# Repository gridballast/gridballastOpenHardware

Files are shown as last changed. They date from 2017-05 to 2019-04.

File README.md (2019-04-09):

# GridBallast
Open Source Water Heater and Plug Load Controller

Please see the [full documentation](https://docs.google.com/document/d/1fPQ65AeftvWFN1sJrpfoSuw6C1mJJdnNV9FeLzjZJOI/edit) here.

## Controller Board
This is the main board that interfaces with the peripherals.
The board integrate the following modules and features:
* ESP32
* U-Blox NEO-M8T GPS Timing Chip
* SX1276 Radio
* USB programming and debugging
* 2.4" OLED display
* 4 way navigation buttons
* Raspberry Pi connectivity
* 60Hz Frequency Monitor
* RS485 and I2C exposed interfaces
* 2000:1 current transformer input
* Amplified microphone input with phantom power
* Leak detector input

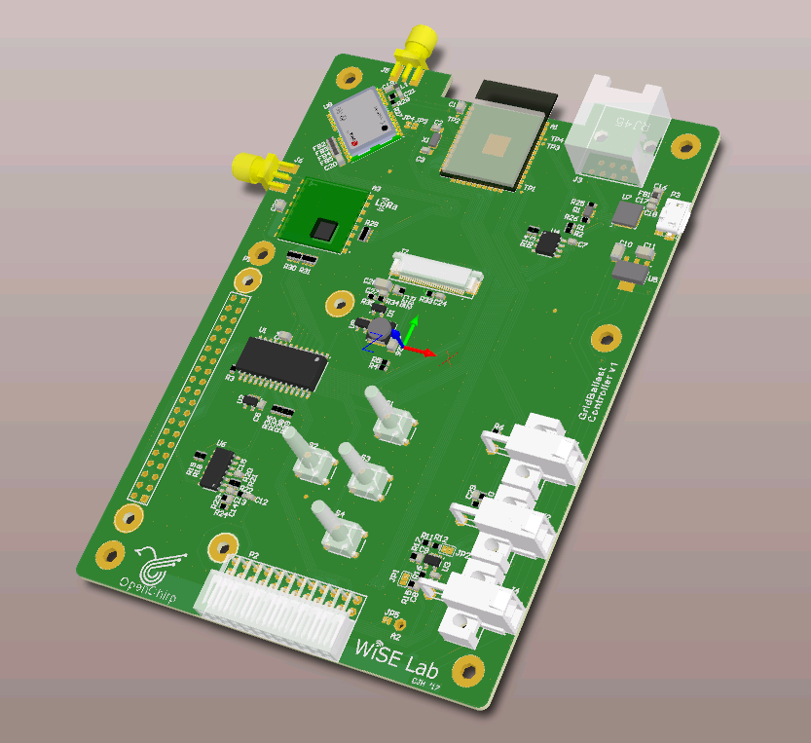
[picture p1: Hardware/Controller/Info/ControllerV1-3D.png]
Controller Board V1 3D


[Interactive 3D View](Hardware/Controller/Info/PCBv1.stl)

## Relay, CT, and Temp Board
This is the accessory board that has two onboard high-power relays, a current transformer, and two analog inputs for temperature sensors.

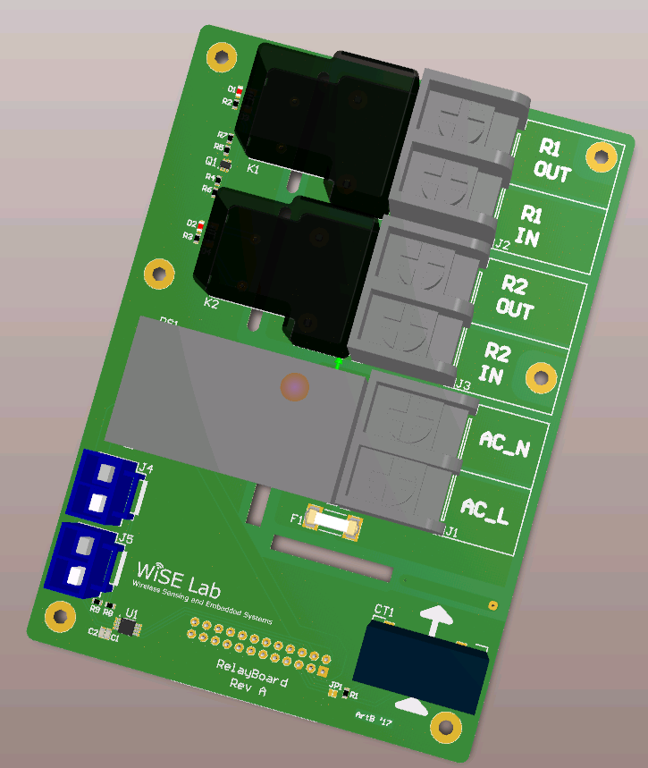
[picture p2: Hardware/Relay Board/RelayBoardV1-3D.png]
Relay Board V1 3D


[Interactive 3D View](Hardware/Relay%20Board/RelayBoardV1.stl)

## CTA2045 and RS485 Board
This small accessory board holds the connector to support CTA2045 and other RS485 communications.
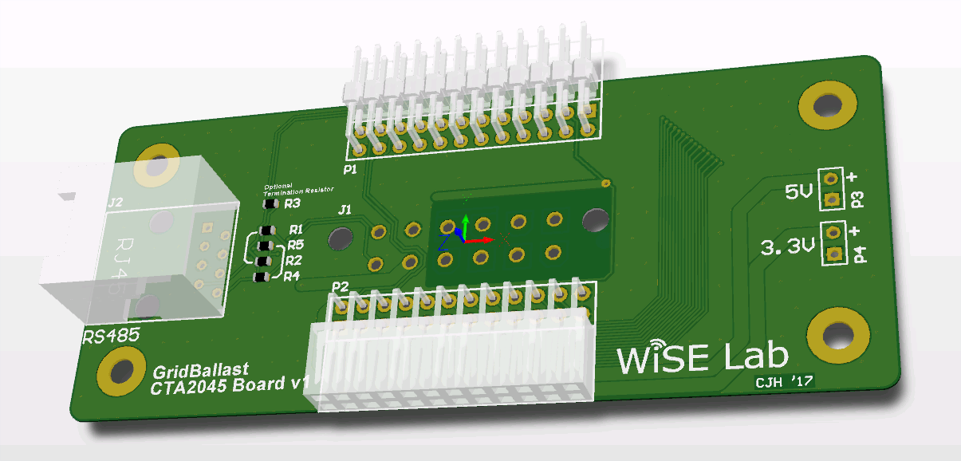
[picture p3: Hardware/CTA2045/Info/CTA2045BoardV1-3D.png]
CTA2045 Board V1 3D


[Interactive 3D View](Hardware/CTA2045/Info/CTA2045v1.stl)

# Getting Started
1. Install the `xtensa-esp32-elf` toolchain by following the instructions here: http://esp-idf.readthedocs.io/en/latest/get-started/#setup-toolchain.
   Make sure the `xtensa-esp32-elf/bin` is added to your `PATH`.
1. Clone the repository
    ```
    $ git clone --recursive https://github.com/WiseLabCMU/gridballast.git
    ```
1. Setup the `IDF_PATH` environment variable by adding the following to your `~/.profile`:
    ```
    export IDF_PATH="<path/to/gridballast>/Support/esp-idf"
    ```
1. Build the controller module
    ```
    $ cd Source/framework
    $ make
    ```
    In the framework configuration, navigate to "Serial flasher config" and select the default serial port. This can be determined by checking which device appears in `/dev` when the controller module is connected via USB. It should start with `/dev/ttyUSB`.
    Save and exit the configuration interface.
1. Flash the controller
    ```
    $ make flash
    ```

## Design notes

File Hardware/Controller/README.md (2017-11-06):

# Description
This is the main appliance controller.

# Fabrication Details
* The main fabrication files and bill of materials are in the [Project Outputs for Controller](Project%20Outputs%20for%20Controller) directory.
* The schematic, pictures, and 3D model are in the [Info](Info) directory.

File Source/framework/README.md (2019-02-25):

# GridBallast

See the README.md file in the upper level 'examples' directory for more information about examples.
This directory is in Support/esp_idf.

# Build Notes
Confirmed to compile on Debian with the lastest compiler, `xtensa-esp32-elf-linux64-1.22.0-80-g6c4433a-5.2.0.tar.gz`,
and the provided `Support/esp-idf` libraries.
`Craig - Feb 25, 2019`

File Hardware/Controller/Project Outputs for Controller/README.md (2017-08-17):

# Board Details
The overall dimensions are 133.2mm x 94mm

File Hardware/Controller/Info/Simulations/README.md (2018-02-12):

# Descriptions
This directory holds the simulation setup and results for some of the more
analog components on the Controller board.

The simulations have been performed in [LTSpice](http://www.linear.com/designtools/software/#LTspice).

# Results Preview

## Microphone and Amplifier with DC Biasing
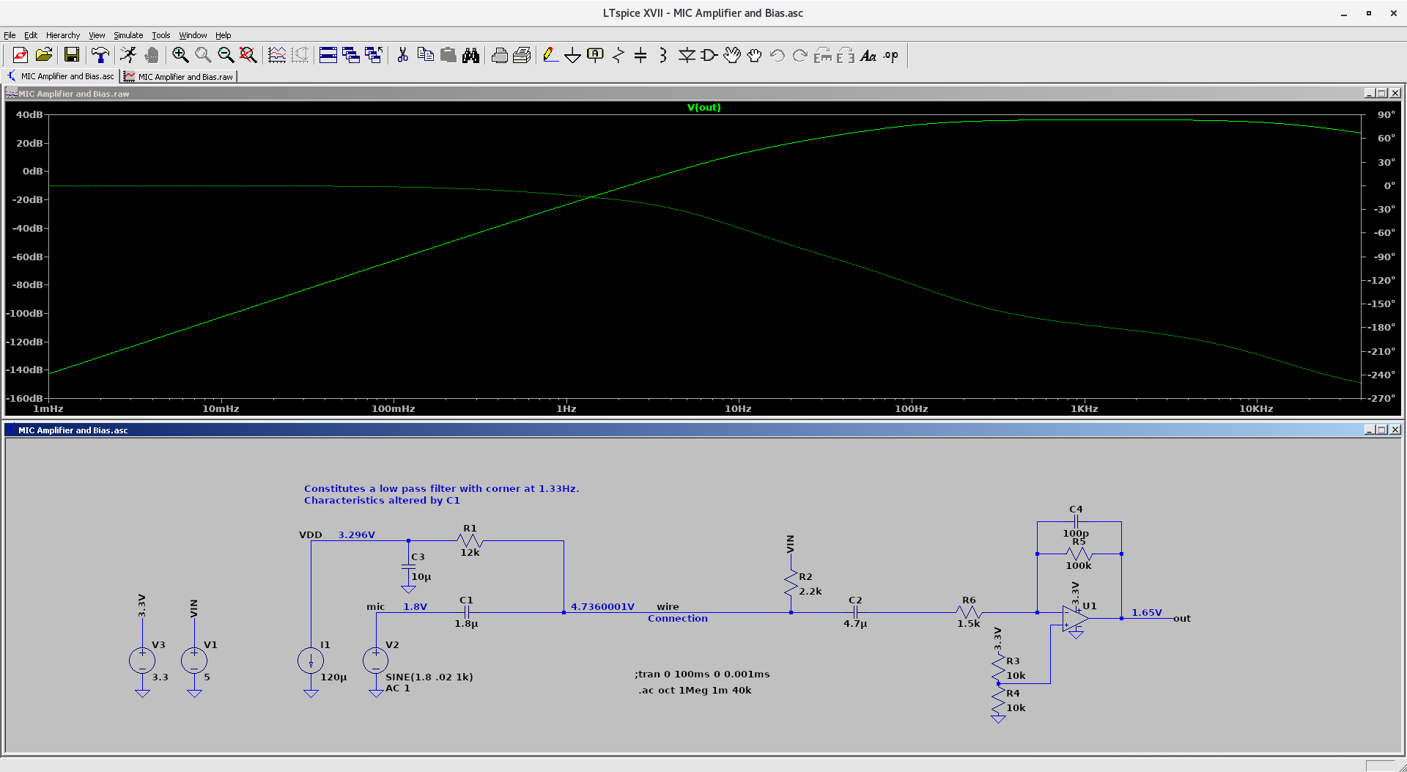
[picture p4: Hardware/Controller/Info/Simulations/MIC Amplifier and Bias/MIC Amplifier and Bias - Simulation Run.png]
MIC Amplifier and Bias


## Current Transformer

### Bias Only - Output Voltage
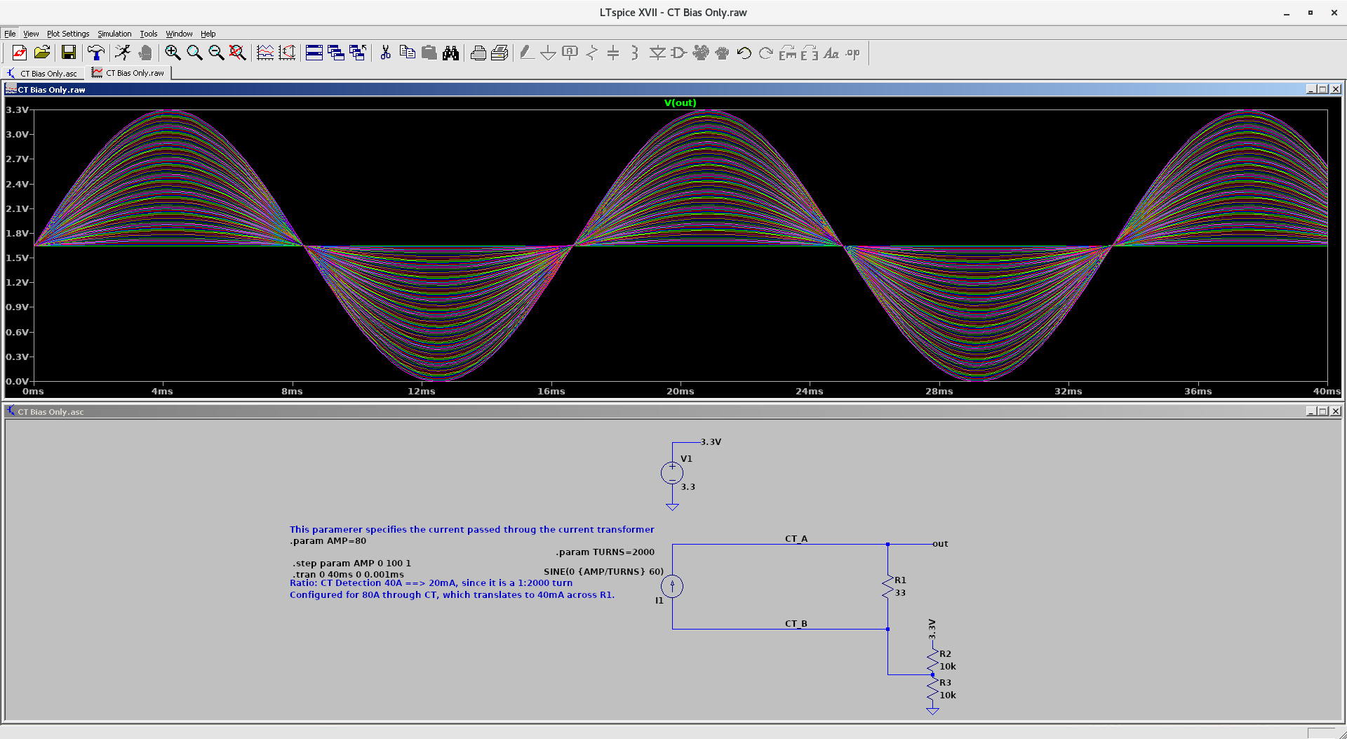
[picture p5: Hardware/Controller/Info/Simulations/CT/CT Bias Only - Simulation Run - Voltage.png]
Voltage


### Bias Only - Current and Output Voltage
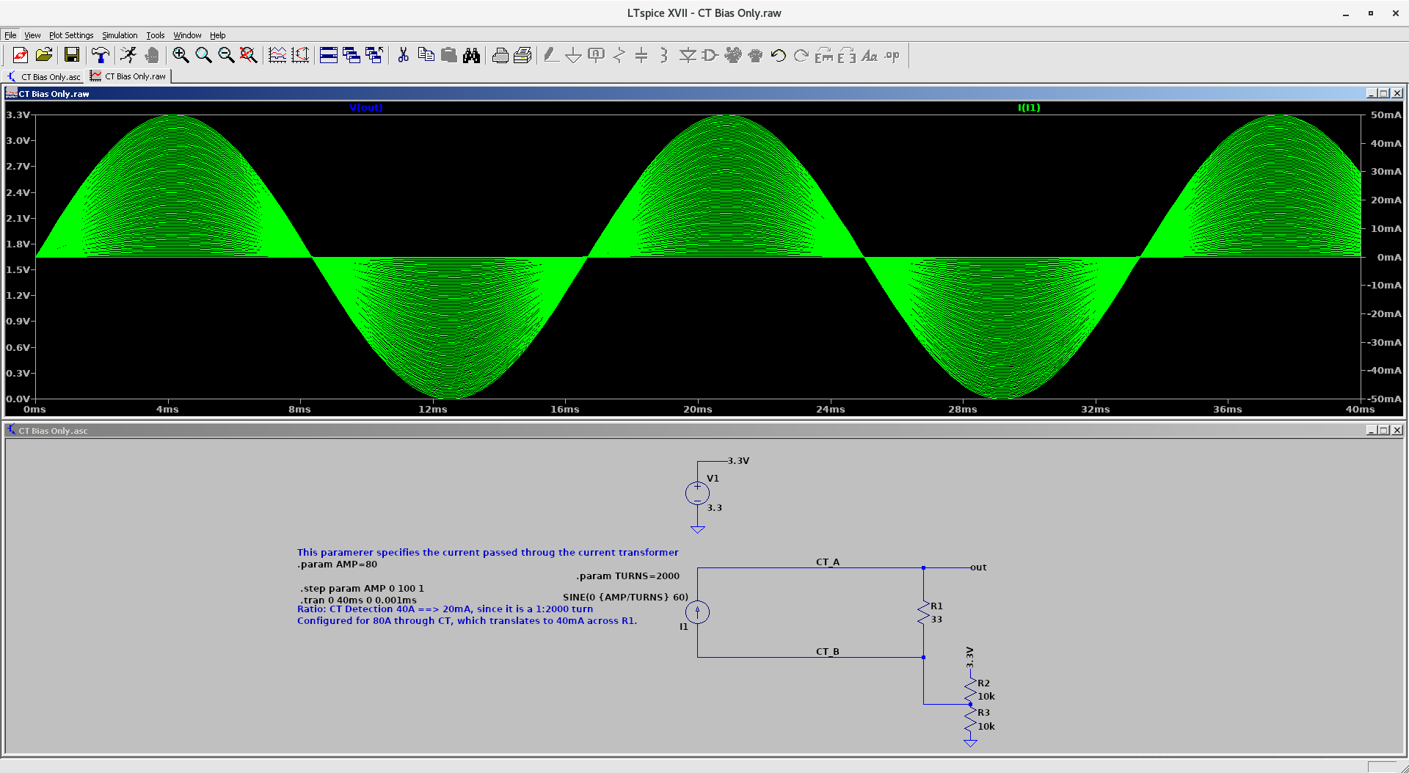
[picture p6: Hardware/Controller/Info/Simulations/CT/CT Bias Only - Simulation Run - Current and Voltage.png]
Current and Voltage


## 60Hz Detector

### Input with Noise
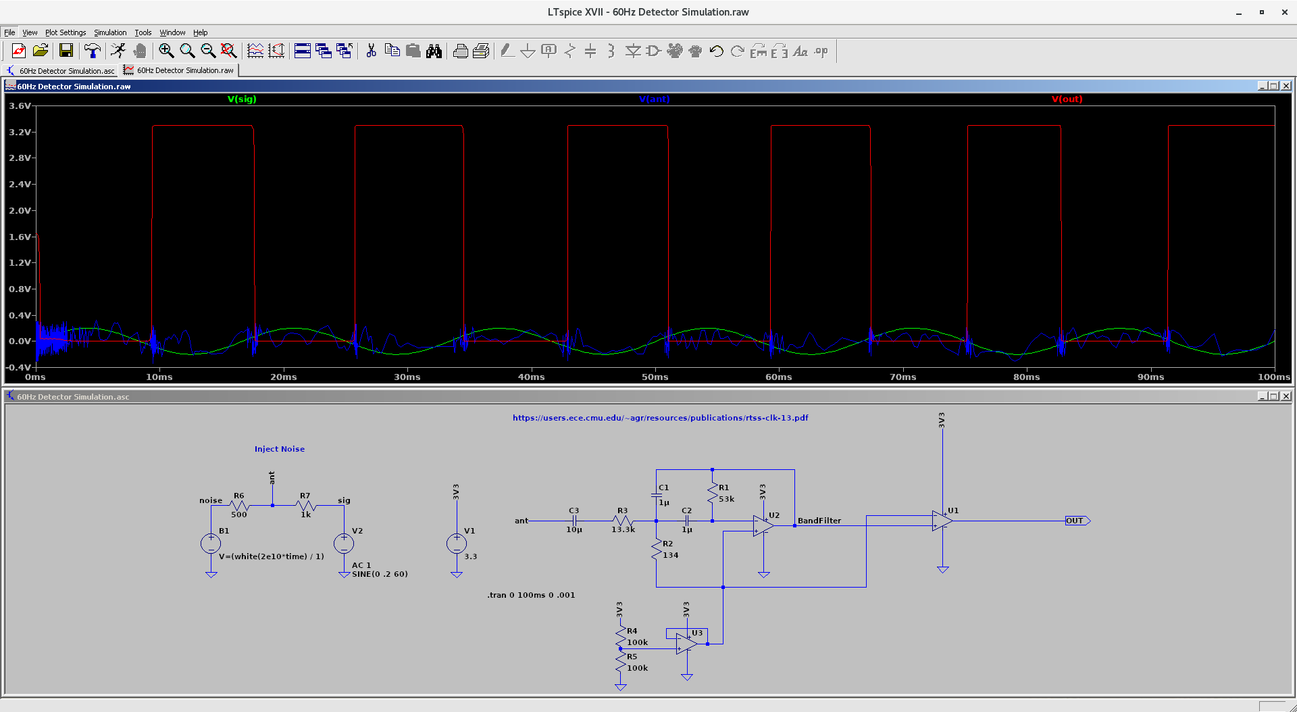
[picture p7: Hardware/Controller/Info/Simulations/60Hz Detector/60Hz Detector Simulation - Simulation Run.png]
Input with Noise


### Frequency Response
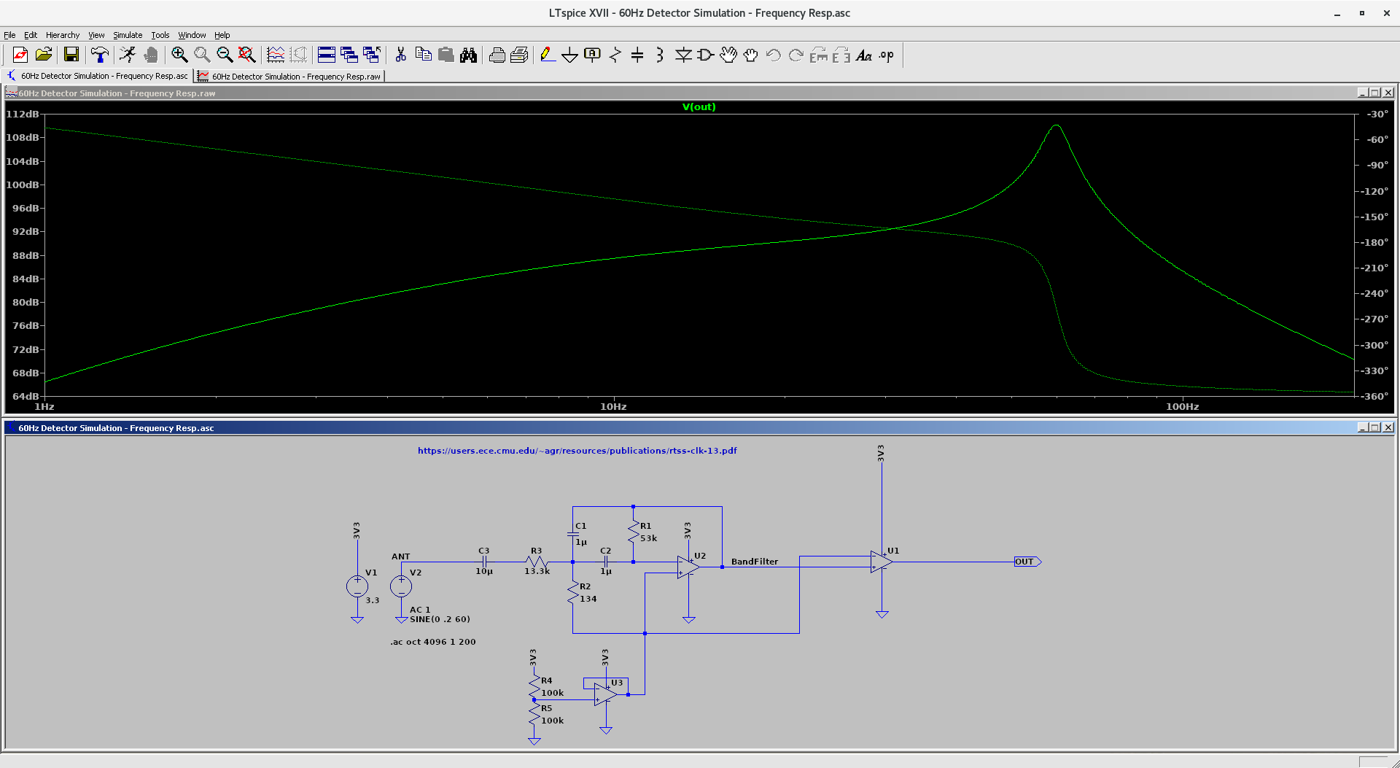
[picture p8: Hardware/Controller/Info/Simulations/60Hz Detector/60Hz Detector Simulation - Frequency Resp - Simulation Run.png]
Frequency Response


## Leak Detection Cable
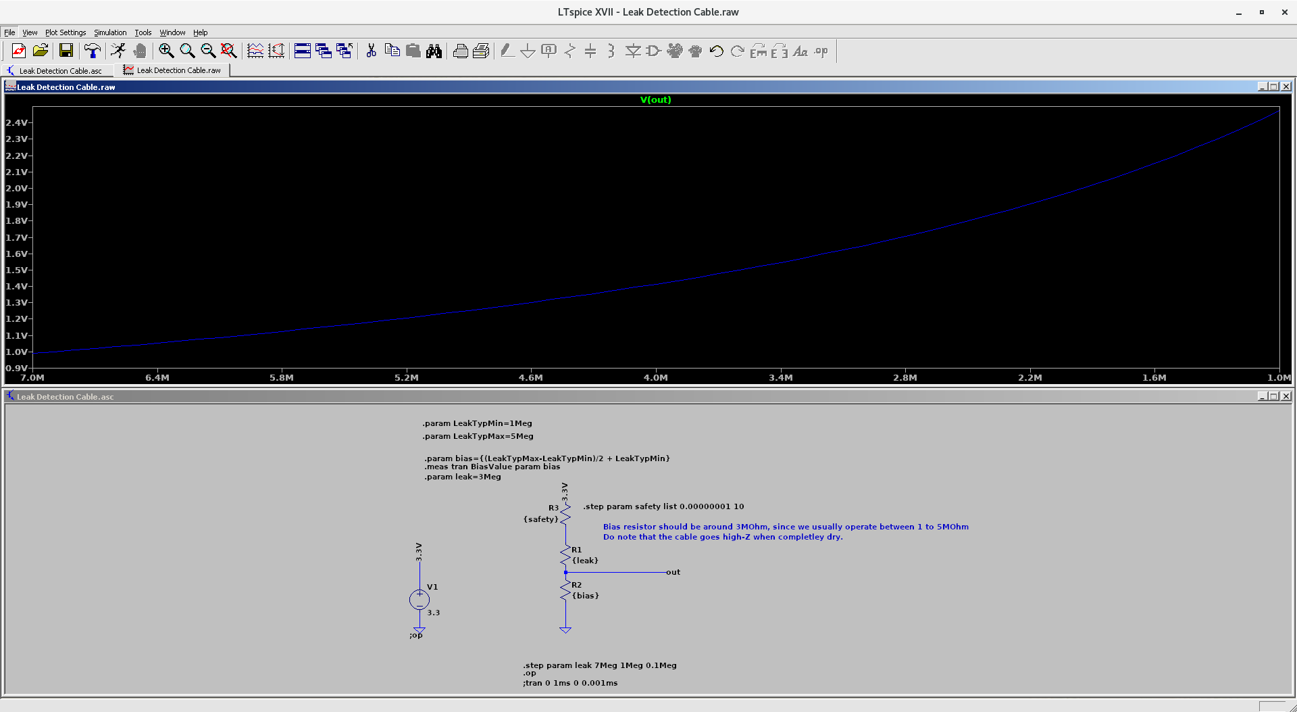
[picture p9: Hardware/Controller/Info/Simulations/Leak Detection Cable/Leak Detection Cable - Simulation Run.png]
Different Biasing Resistors


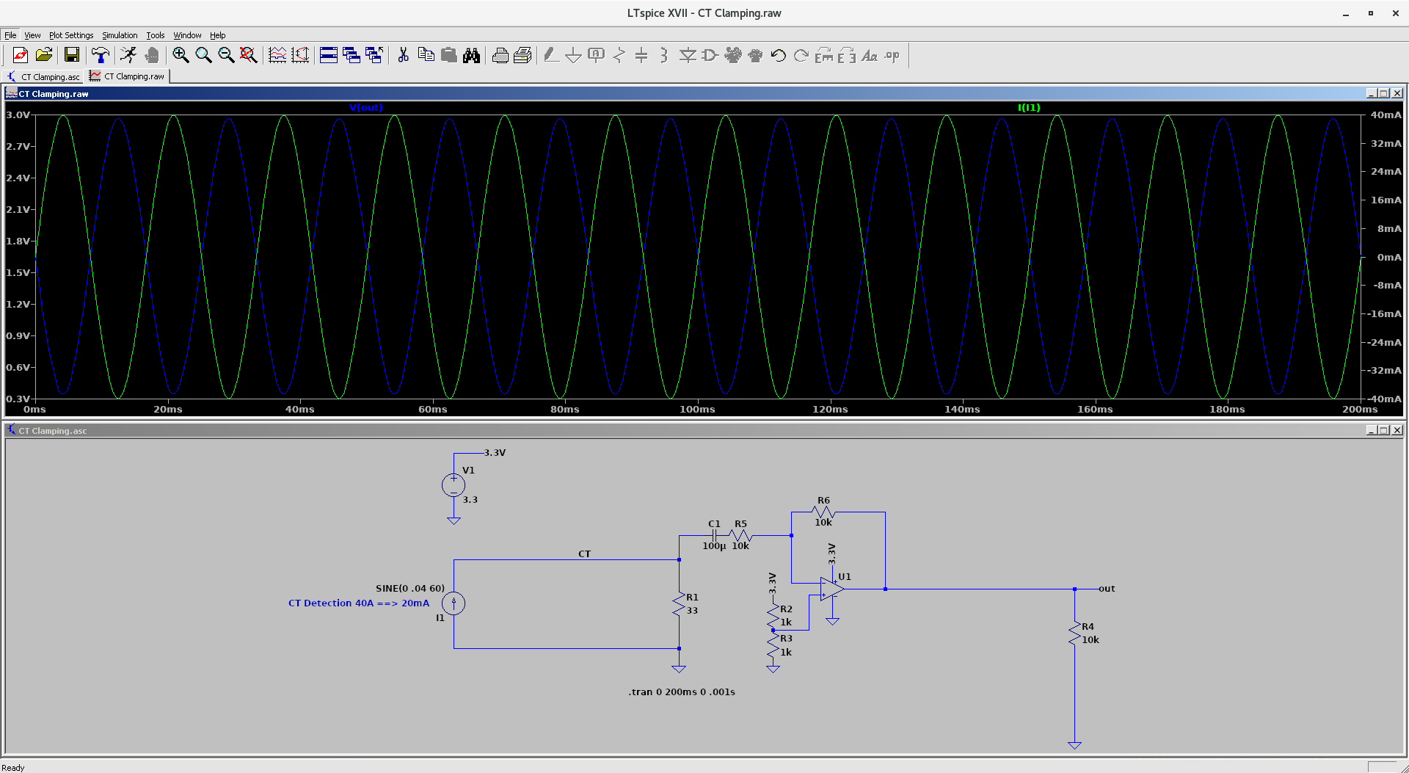
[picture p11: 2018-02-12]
Hardware/Controller/Info/Simulations/CT/CT Clamping - Simulation Run.png

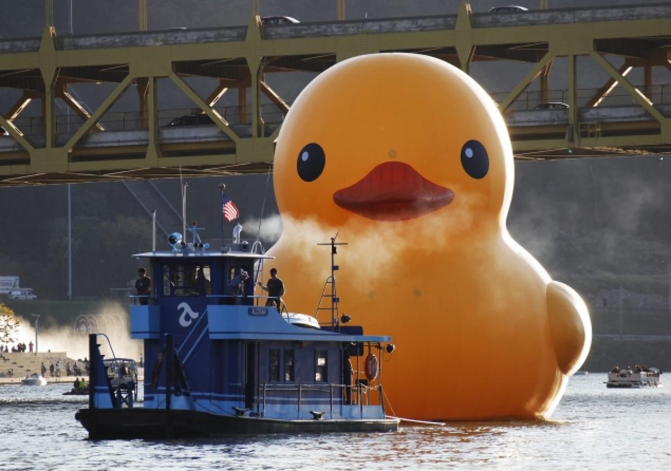
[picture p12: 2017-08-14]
Hardware/Controller/Info/ThePittsburghDuck.jpg

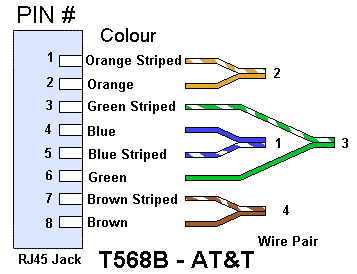
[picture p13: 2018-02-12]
Hardware/Controller/Info/CAT5-RJ45-Pairs.png

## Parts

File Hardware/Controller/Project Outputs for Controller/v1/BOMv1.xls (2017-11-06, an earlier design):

Comment | Description | Designator | LibRef | Manufacturer 1 | Manufacturer 2 | Manufacturer 3 | Manufacturer Part Number 1 | Manufacturer Part Number 2 | Manufacturer Part Number 3 | Quantity
ESP-WROOM-32 | ESP WROOM 32 Module | A1 | ESP-WROOM-32 | Adafruit Industries LLC |  |  | 3320 |  |  | 1
HopeRF RFM95 | HopeRF RFM95 915MHz LoRa Radio | A3 | RFM95 | Seeed Technology Co., Ltd | RF Solutions |  | 109990166 | RFM95W-915S2 |  | 1
22uF | SMT 0805 Ceramic Capacitor | C1 | CAP0805 22uF 10% 6.3V X5R | Samsung Electro-Mechanics America, Inc. | Yageo |  | CL21A226KQCLRNC | CC0805KKX5R5BB226 |  | 1
CAP 7pF 50V 0603(1608) | CAP 7pF 50V ±10% 0603 (1608 Metric) Thickness 1mm SMD | C2, C3 | CMP-1035-00607-1 | Samsung Electro-Mechanics America, Inc. | Yageo | AVX | CL10C070CB8NNNC | CC0603DRNPO9BN7R0 | 06035A7R0CAT2A | 2
10uF | SMT 0805 Ceramic Capacitor | C4, C20, C22, C26 | CAP0805 10uF 10% 6.3V X5R | Samsung Electro-Mechanics America, Inc. |  |  | CL21A106KQFNNNG |  |  | 4
10000pF | SMT 0603 Ceramic Capacitor | C5, C6, C15, C21 | CAP0603 10000pF 10% 50V X7R | AVX Corporation | Yageo | Murata Electronics North America | 06035C102KAT2A | CC0603KRX7R9BB102 | GRM188R71H102KA01D | 4
4.7uF | SMT 0603 Ceramic Capacitor | C7, C8 | CAP0603 4.7uF 10% 6.3V X7R | Samsung Electro-Mechanics America, Inc. |  |  | CL10B475KQ8NQNC |  |  | 2
100pF | SMT 0603 Ceramic Capacitor | C9, C16, C17, C18 | CAP0603 100pF 5% 50V NP0 | KEMET | Murata Electronics North America |  | C0603C101J5GACTU | GRM1885C1H101JA01D |  | 4
4.7uF | SMT 1206 Ceramic Capacitor | C10, C11 | CAP1206 4.7uF 10% 25V X5R | Taiyo Yuden |  |  | TMK316BJ475KL-T |  |  | 2
10uF | SMT 0603 Ceramic Capacitor | C12, C29 | CAP0603 10uF 20% 6.3V X5R | Taiyo Yuden | Murata Electronics North America |  | JMK107BJ106MA-T | GRM188R60J106ME47D |  | 2
1uF | SMT 0603 Ceramic Capacitor | C13, C14, C24 | CAP0603 1uF 10% 10V X7R | Samsung Electro-Mechanics America, Inc. | AVX Corporation |  | CL10B105KP8NNNC | 0603ZC105JAT2A |  | 3
47pF | SMT 0603 Ceramic Capacitor | C19 | CAP0603 47pF 5% 50V NP0 | Samsung Electro-Mechanics America, Inc. | Samsung Electro-Mechanics America, Inc. |  | CL10C470JB8NNNC | CL10C470JB8NCNC |  | 1
2.2uF | SMT 0603 Ceramic Capacitor | C25 | CAP0603 2.2uF 10% 6.3V X7R | Samsung Electro-Mechanics America, Inc. | Yageo |  | CL10B225KQ8NFNC | CC0603KRX7R5BB225 |  | 1
0.1uF | SMT 0603 Ceramic Capacitor | C27 | CAP0603 0.1uF 10% 25V X7R | Yageo | Murata Electronics North America |  | CC0603KRX7R8BB104 | GRM188R71E104KA01D |  | 1
10uF | SMT 1206 Ceramic Capacitor | C28 | CAP1206 10uF 10% 16V X5R | Samsung Electro-Mechanics America, Inc. | Murata Electronics North America |  | CL31A106KOHNNNE | GRM31CR71C106KA12L |  | 1
BAT54 Schottky Diode | ON Semi BAT54 800mV Schottky Diode | D1 | BAT54 | ON Semiconductor | Vishay Semiconductors |  | BAT54SLT1G | BAT54 |  | 1
Feritte Bead 62Ohm |  | FB1 | FB0603 62Ohm | Wurth Electronics Inc. |  |  | 782633620 |  |  | 1
Feritte Bead 1kOhm |  | FB2, FB3, FB4, FB5 | FB0603 1kOhm | Murata Electronics North America |  |  | BLM18AG102SN1D |  |  | 4
4.2mm Pitch 2 Position Connector | TE 1586043-2 - 2position 4.2mm pitch right angle with screw support | J1, J2, J4 | 2POS 4.2mm Pitch Right Angle | TE Connectivity AMP Connectors |  |  | 1586043-2 |  |  | 3
RJ45 Connector | Amphenol RJ45 Unshielded Through-Hole Connector | J3 | RJ45 Unshielded PTH Connector | Amphenol FCI | Amphenol FCI |  | 54601-908WPLF | 54601-908WPLF |  | 1
SMA Edge Connector | SMA Edge Connector | J5, J6 | SMA Edge Connector | RF Solutions | Taoglas Limited | Taoglas Limited | CON-SMA-EDGE-S | EMPCB.SMAFSTJ.C.HT | EMPCB.SMAFSTJ.B.HT | 2
31Pos FlatFlex Connector | TE 3-1734839-1 31 Position Flat Flex ZIF Connector | J7 | 31 Position Flat Flex ZIF Connector | TE Connectivity AMP Connectors |  |  | 3-1734839-1 |  |  | 1
27nH | SMT 0603 Ceramic Inductor | L1 | IND0603 27nH 400mA 5% 650mOhm 1.7GHz | Wurth Electronics Inc. |  |  | 744786127A |  |  | 1
10uH | SMT Wire Wound Inductor | L2 | INDWW 10uH 1.45A 20% 144mOhm 24MHz | Taiyo Yuden | Taiyo Yuden |  | NRS5020T100MMGJ | NRS5020T100MMGJ |  | 1
0.1" Pitch, 2 Row, 24 Pos, Female, Right-Angle | Sullins 0.1" 2 row 24 position female right-angle header | P2 | 0.1" 2 row 24 position female right-angle header sullins | Sullins Connector Solutions | Sullins Connector Solutions |  | PPTC122LJBN-RC | PPPC122LJBN-RC |  | 1
USB? | Micro USB Type B Port | P3 | MicroUSB TypeB | Amphenol FCI |  |  | 10118192-0001LF |  |  | 1
Dual 3904 NPN | 3904 Dual NPN Transistor | Q1 | MBT3904DW1T1G | ON Semiconductor | ON Semiconductor |  | MBT3904DW1T1G | SMBT3904DW1T1G |  | 1
10K | SMT 0603 Ceramic Resistor | R1, R2, R3, R11, R12, R36, R37, R38, R39 | RES0603 10K 1% 1/10W | Yageo | Stackpole Electronics Inc. | Panasonic Electronic Components | RC0603FR-0710KL | RMCF0603FT10K0 | ERJ-3EKF1002V | 9
4.7K | SMT 0603 Ceramic Resistor | R4, R5, R33 | RES0603 4.7K 1% 1/10W | Yageo | Panasonic Electronic Components | Stackpole Electronics Inc. | RC0603FR-074K7L | ERJ-3EKF4701V | RMCF0603FT4K70 | 3
10 | SMT 0603 Ceramic Resistor | R6, R28 | RES0603 10 1% 1/10W | Yageo | Stackpole Electronics Inc. | Bourns Inc. | RC0603FR-0710RL | RMCF0603FT10R0 | CR0603-FX-10R0ELF | 2
3M | SMT 0603 Ceramic Resistor | R7 | RES0603 3M 1% 1/10W | Vishay Dale | Stackpole Electronics Inc. | Samsung Electro-Mechanics America, Inc. | CRCW06033M00FKEA | RMCF0603FT3M00 | RC1608F305CS | 1
33 | SMT 0603 Ceramic Resistor | R8 | RES0603 33 1% 1/10W | Yageo | Stackpole Electronics Inc. | Panasonic Electronic Components | RC0603FR-0733RL | RMCF0603FT33R0 | ERJ-3EKF33R0V | 1
1K | SMT 0603 Ceramic Resistor | R9, R10, R27 | RES0603 1K 1% 1/10W | Yageo | Panasonic Electronic Components | Stackpole Electronics Inc. | RC0603FR-071KL | ERJ-3EKF1001V | RMCF0603FG1K00 | 3
2.43K | SMT 0603 Ceramic Resistor | R13 | RES0603 2.43K 1% 1/10W | Yageo | Yageo |  | RC0603FR-072K43L | RC0603FR-072K43L |  | 1
4.32K | SMT 0603 Ceramic Resistor | R14 | RES0603 4.32K 1% 1/10W | Yageo | Panasonic Electronic Components | Vishay Dale | RC0603FR-074K32L | ERJ-3EKF4321V | CRCW06034K32FKEB | 1
2.2K | SMT 0603 Ceramic Resistor | R15 | RES0603 2.2K 1% 1/10W | Yageo |  |  | RC0603FR-072K2L |  |  | 1
1.5k | SMT 0603 Ceramic Resistor | R16 | RES0603 1.5K 1% 1/10W | Yageo | Stackpole Electronics Inc. |  | RC0603FR-071K5L | RMCF0603FT1K50 |  | 1
100K | SMT 0603 Ceramic Resistor | R17, R18, R19 | RES0603 100K 1% 1/10W | Yageo |  |  | RC0603FR-07100KL |  |  | 3
43 | SMT 0603 Ceramic Resistor | R20 | RES0603 43 1% 1/10W | Yageo | Panasonic Electronic Components |  | RC0603FR-0743RL | ERJ-3EKF43R0V |  | 1
91 | SMT 0603 Ceramic Resistor | R21 | RES0603 91 1% 1/10W | Yageo | Vishay Dale | Rohm Semiconductor | RC0603FR-0791RL | CRCW060391R0FKEA | MCR03ERTF91R0 | 1
13.3K | SMT 0603 Ceramic Resistor | R22 | RES0603 13.3K 1% 1/10W | Yageo | Panasonic Electronic Components |  | RC0603FR-0713K3L | ERJ-3EKF1332V |  | 1
28K | SMT 0603 Ceramic Resistor | R23, R24 | RES0603 28K 0.1% 1/10W | Yageo | Panasonic Electronic Components |  | RT0603BRE0728KL | ERA-3AEB2802V |  | 2
12K | SMT 0603 Ceramic Resistor | R25, R26 | RES0603 12K 1% 1/10W | Yageo | Stackpole Electronics Inc. |  | RC0603FR-0712KL | RMCF0603FT12K0 |  | 2
100 |  | R29, R30, R31 | RESARR1206 100 5% 1/16W | Yageo |  |  | YC164-JR-07100RL |  |  | 3
910K | SMT 0603 Ceramic Resistor | R32 | RES0603 910K 1% 1/10W | Yageo | Panasonic Electronic Components | Stackpole Electronics Inc. | RC0603FR-07910KL | ERJ-3EKF9103V | RMCF0603FT910K | 1
205K | SMT 0603 Ceramic Resistor | R34 | RES0603 205K 1% 1/10W | Yageo | Panasonic Electronic Components | Vishay Dale | RC0603FR-07205KL | ERJ-3EKF2053V | CRCW0603205KFKEA | 1
23.2K | SMT 0603 Ceramic Resistor | R35 | RES0603 23.2K 1% 1/10W | Yageo | Vishay Dale | Stackpole Electronics Inc. | RC0603FR-0723K2L | CRCW060323K2FKEA | RMCF0603FG23K2 | 1
17mm Tactile Switch | TE 3-1825910-1 17mm Tactile Switch | S1, S2, S3, S4 | TE 3-1825910-1 17mm Tactile Switch | TE Connectivity ALCOSWITCH Switches |  |  | 3-1825910-1 |  |  | 4
I2C 16CH IO Expander | Microchip MCP23017 I2C 16CH IO Expander | U1 | MCP23017T-E/SO | Microchip Technology |  |  | MCP23017T-E/SO |  |  | 1
Single OR Gate | Fairchild/ON Semi NC7S32M5X Single OR Gate | U2 | NC7S32M5X | Fairchild/ON Semiconductor |  |  | NC7S32M5X |  |  | 1
88MHz Single OP-Amp | TI LMV793MF/NOPB 88MHz Single OP-Amp | U3 | LMV793MF/NOPB | Texas Instruments |  |  | LMV793MF/NOPB |  |  | 1
TI SN65176B | Half Duplex RS485 Tranceiver | U4 | SN65176B | Texas Instruments | Texas Instruments |  | SN65176BDR | SN65176BDR |  | 1
AP2114H-3.3TRG1 | AP2114 3.3V Fixed LDO Regulator | U5 | AP2114H-3.3TRG1 | Diodes Incorporated |  |  | AP2114H-3.3TRG1 |  |  | 1
1MHz Quad OP-Amp | ON Semi LM324DR2G 1MHz Quad OP-Amp | U6 | LM324DR2G | ON Semiconductor |  |  | LM324DR2G |  |  | 1
FT232RQ-Reel | USB UART Asynchronous Serial Data Transfer Chip, 32-pin QFN, Tape and Reel | U7 | FT232RQ-Reel | FTDI |  |  | FT232RQ-Reel |  |  | 1
NEO-M8T | u-blox NEO GNSS module | U8 | NEO | U-Blox |  |  | NEO-M8T |  |  | 1
FAN5331 Boost Converter | ON Semi FAN5531 Boost Converter | U9 | FAN5331 | Fairchild/ON Semiconductor | Rochester Electronics |  | FAN5331SX | FAN5331SX |  | 1
14340272-32.768KHz | Crystal, 32.768 KHz, -40 to 85 degC, 3.2 x 1.5 x 0.9 mm SMD | X1 | CMP-0463-00001-2 | Abracon | ECS |  | ABS07-32.768KHZ-7-1-T | ECS-.327-7-34B-C-TR |  | 1

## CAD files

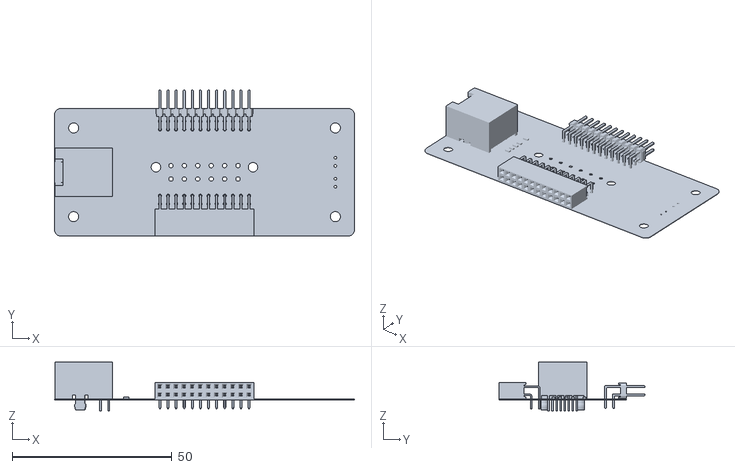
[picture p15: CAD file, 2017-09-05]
Hardware/CTA2045/Info/CTA2045v1.stl
94.0 x 45.8 x 15.3

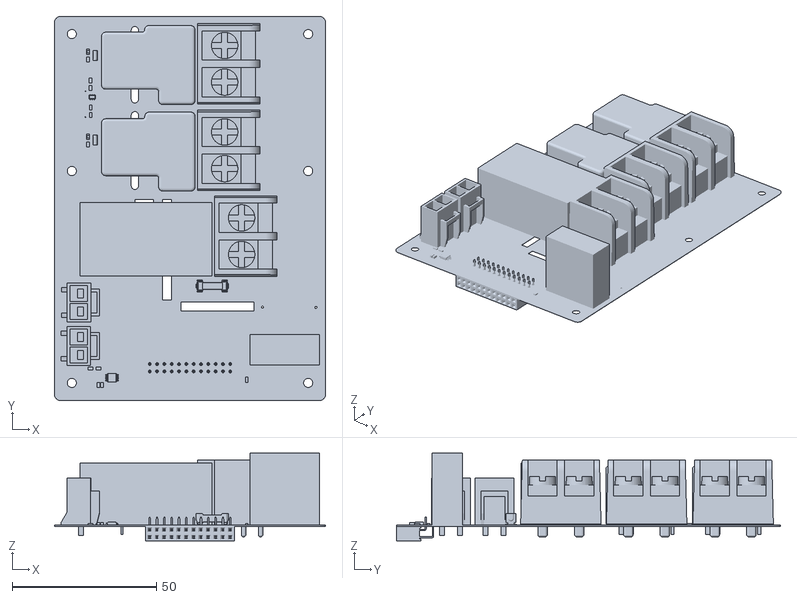
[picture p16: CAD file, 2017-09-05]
Hardware/Relay Board/RelayBoardV1.stl
94.0 x 133.2 x 30.5

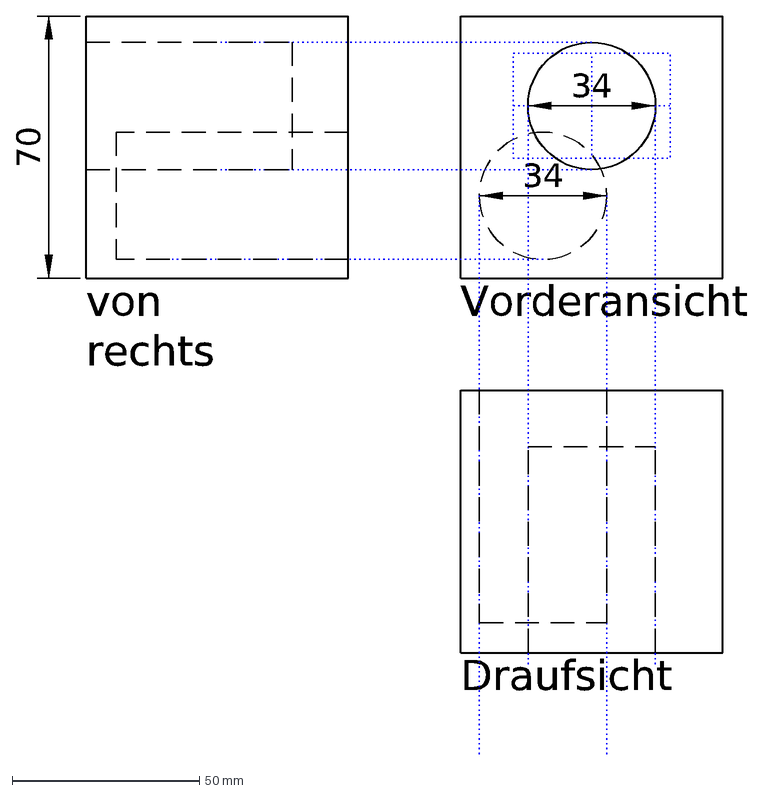
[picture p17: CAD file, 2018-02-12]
Source/framework/main/u8g2/sys/arm/stm32l031x6/clock_cube.dxf
Draufsicht
Vorderansicht
von rechts
70
34

Source/framework/main/u8g2/sys/arm/stm32l031x6/clock_2.dxf
65
Draufsicht
Vorderansicht
von unten
von rechts
von links
14
30
32
35
75
55
10
12
16
11
22
34
28
29
18
93
19
43
15
68
60
57
150
Holzbohrer: 2.5, 8, 10, 12, 16, 32mm
8
7
6
2.5mm

Source/framework/main/u8g2/sys/arm/stm32l031x6/clock.dxf
65
32
28
16
Draufsicht
Vorderansicht
von unten
von rechts
von links
14
6
45
60
30
20
8
35
75
55
10
12

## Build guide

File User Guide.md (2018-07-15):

# Grid Ballast User Guide
## Contents

  - [Setup](#setup)
    - [System Overview](#system-overview)
    - [Hardware](#hardware)
    - [Installation](#installation)
    - [Getting Started - Toolchain](#getting-started-toolchain)
    - [Runtime Network Configuration](#runtime-network-configuration)
    - [User Interface](#user-interface)
    - [OpenChirp Setup](#openchirp-setup)
  - [Technical](#technical)
    - [Overview](#overview)
    - [Specifications](#specifications)
    - [Firmware](#firmware)
    - [Cloud Architecture](#cloud-architecture)

## Setup
### System Overview
At a high-level, the Grid Ballast hardware can be used for supporting two classes of devices: 

**1. Thermostatically controlled loads (TCLs)** :TCLs like waterheaters, pool heaters, refrigerators, and HVAC systems, can use set-point manipulation to store energy or delay usage.

**OR**

**2.Miscellaneous plug loads**:  Plug loads like lighting and appliances (washer, dryer,dishwasher, etc.) typically only support binary control, but theiruse may be delayed and their usage patterns can be of benefit toutilities.

Grid Ballast System Overview

_Grid Ballast System Overview_

### Hardware
The Grid Ballast hardware platform consists of the following hardware:
- _Main Controller Board_
- _CTA-2045 Board_: to control appliances with built-in CTA-2045 interface
- _Relay Board_: to control miscellaneous plug loads using hardware retrofit
- _Micro USB cable_: to flash firmware
- _Ethernet Cable_: to connect Controller board and CTA-2045 board using RJ45 interface

### Installation
**Assembly with CTA-2045 based Electronic Thermostat**
APCOM EC-100 Wiring Diagram


_Grid Ballast Test System implemented on a residential Rheem Water Heater(cta 20145 enabled)_

**Assembly with mechanical retrofit**
Mechanical Retrofit

### Getting Started - Toolchain

1. Install the `xtensa-esp32-elf` toolchain by following the instructions here: http://esp-idf.readthedocs.io/en/latest/get-started/#setup-toolchain.
   Make sure the `xtensa-esp32-elf/bin` is added to your `PATH`.
1. Clone the repository
    ```
    $ git clone --recursive https://github.com/WiseLabCMU/gridballast.git
    ```
1. Setup the `IDF_PATH` environment variable by adding the following to your `~/.profile`:
    ```
    export IDF_PATH="<path/to/gridballast>/Support/esp-idf"
    ```
1. Build the controller module
    ```
    $ cd Source/framework
    $ make
    ```
    In the framework configuration, navigate to "Serial flasher config" and select the default serial port. This can be determined by checking which device appears in `/dev` when the controller module is connected via USB. It should start with `/dev/ttyUSB`.
    Save and exit the configuration interface.
1. Flash the controller
    ```
    $ make flash
    ```
    
### Runtime Network Configuration
The WiFi SSID and password can be configured at runtime (without recompiling and reflashing the module). Other parameters could be added as necessary.
Configuration parameters are stored in flash using the [NVS Library](http://esp-idf.readthedocs.io/en/latest/api-reference/storage/nvs_flash.html).
On initialization of the wifi module, if stored wifi configuration parameters exist, they are loaded and used to connect to wifi.
If no parameters exist, the module launches configuration mode.

In configuration mode, the module broadcasts a wifi network named "gridballast". A user can connect to the gridballast network and open
http://[module-ip]/ (by default 192.168.1.4, can be found programatically with `tcpip_adapter_get_ip_info`) in a web browser. The module will present a webpage where the SSID and password can be configured.
To exit configuration mode, the module must be rebooted.

### User Interface

If the default code from the [GridBallast Github](https://github.com/WiseLabCMU/gridballast) is flashed into the board, the following user-selectable menus will be displayed on the LCD.


_Menu 1: Water Heater vitals_


_Menu 2: User selectable options_


_Menu 3: Runtime Network Configuration_

### OpenChirp Setup

The OpenChirp platform can be used for control and visualization of the Controller parameters and measurements. Setup information can be found [here](https://github.com/OpenChirp/docs/wiki/time-series-database).

Here are snapshots of time series visualizations from OpenChirp for the Grid Ballast test system.

Grid Frequency Measurement

Top and Bottom Temperature measurements

## Technical
### Overview
The open-source controller hardware is based around the Espressif Systems ESP32 microcontroller which has a connector for anexternal Raspberry Pi. The ESP32 is a single chip 2.4 GHz Wi-Fiand Bluetooth combination that provides a low-cost 240 MHz dualcore Tensilica LX6 processor with 520 KB of SRAM and 4 MByte offlash. The integrated wireless transceiver supports 802.11bgn witha stack that allows it to operate in both client, WiFi direct and APmodes to simplify installation. The chip comes with support forWEP, WPA/WPA2 PSK/Enterprise security with hardware accelerated encryption for AES / SHA2 / ECC and RSA-4096 standards.

Hardware Architecture

_Hardware Architecture_

### Specifications
- Physical Dimensions:
- Power Supply: 100- 270 VAC at 50/60 Hz
- Frequency measurement: 45 - 65 Hz, Resolution of 4 s (user-definable)
- Power Consumption: average current 200mA @ 3.3 V
- Operating temperature: 
- Heating Coil Relay: 2 x 40 Amps at 240VAC
- Number of lifetime Switching Operations: 100,000 minimum at 1,800 operations/hr
- item

### Firmware
We use multiple tasks running on FreeRTOS to manage four mainsoftware tasks: water heater control, grid frequency estimation,user interaction, and communication. We developed a comprehen-sive library for different applications and multiple communication protocols (WiFi, LoRa and BLE) to interact with our Cloud-based management system. The firmware simplifies adding additionalfunctionality and interfaces while providing a GUI and connectivity options. Our software is available on [GridBallast Github](https://github.com/WiseLabCMU/gridballast/tree/softap-config-mode)  and compiled using a standard GCC toolchain.

Firmware Architecture
_Firmware Architecture_

### Cloud Architecture

In support of wide-area control of multiple water heaters, we leverage the [OpenChirp](https://openchirp.io/) framework for device management, data processing, and visualization. OpenChirp provides communication with end devices over multiple secure protocols, the facility to process data in real time, and the capabilities to manage groups of devices. In our design, the GridBallast controller communicates with OpenChirp using REST over WiFi and LoRaWANin a polling fashion. OpenChirp then stores this data in a time-series database and exposes it to other applications using REST andMQTT. The system also provides DeviceGroups that can be used to dispatch control commands across multiple water heaters.

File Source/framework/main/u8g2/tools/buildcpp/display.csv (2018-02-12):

# 1. device name
# 2. pinset
# 3. constructor name w/o prefix
u8x8_d_ssd1306_128x64_noname | 4WSWSPI | SSD1306_128X64_4W_SW_SPI
u8x8_d_ssd1306_128x64_noname | 4WHWSPI | SSD1306_128X64_4W_HW_SPI
u8x8_d_ssd1306_128x64_noname | 3WSWSPI | SSD1306_128X64_3W_SW_SPI
u8x8_d_ssd1306_128x64_noname | SSDSWI2C | SSD1306_128X64_SW_I2C
u8x8_d_ssd1306_128x64_noname | 6800 | SSD1306_128X64_6800
u8x8_d_ssd1306_128x64_noname | 8080 | SSD1306_128X64_8080

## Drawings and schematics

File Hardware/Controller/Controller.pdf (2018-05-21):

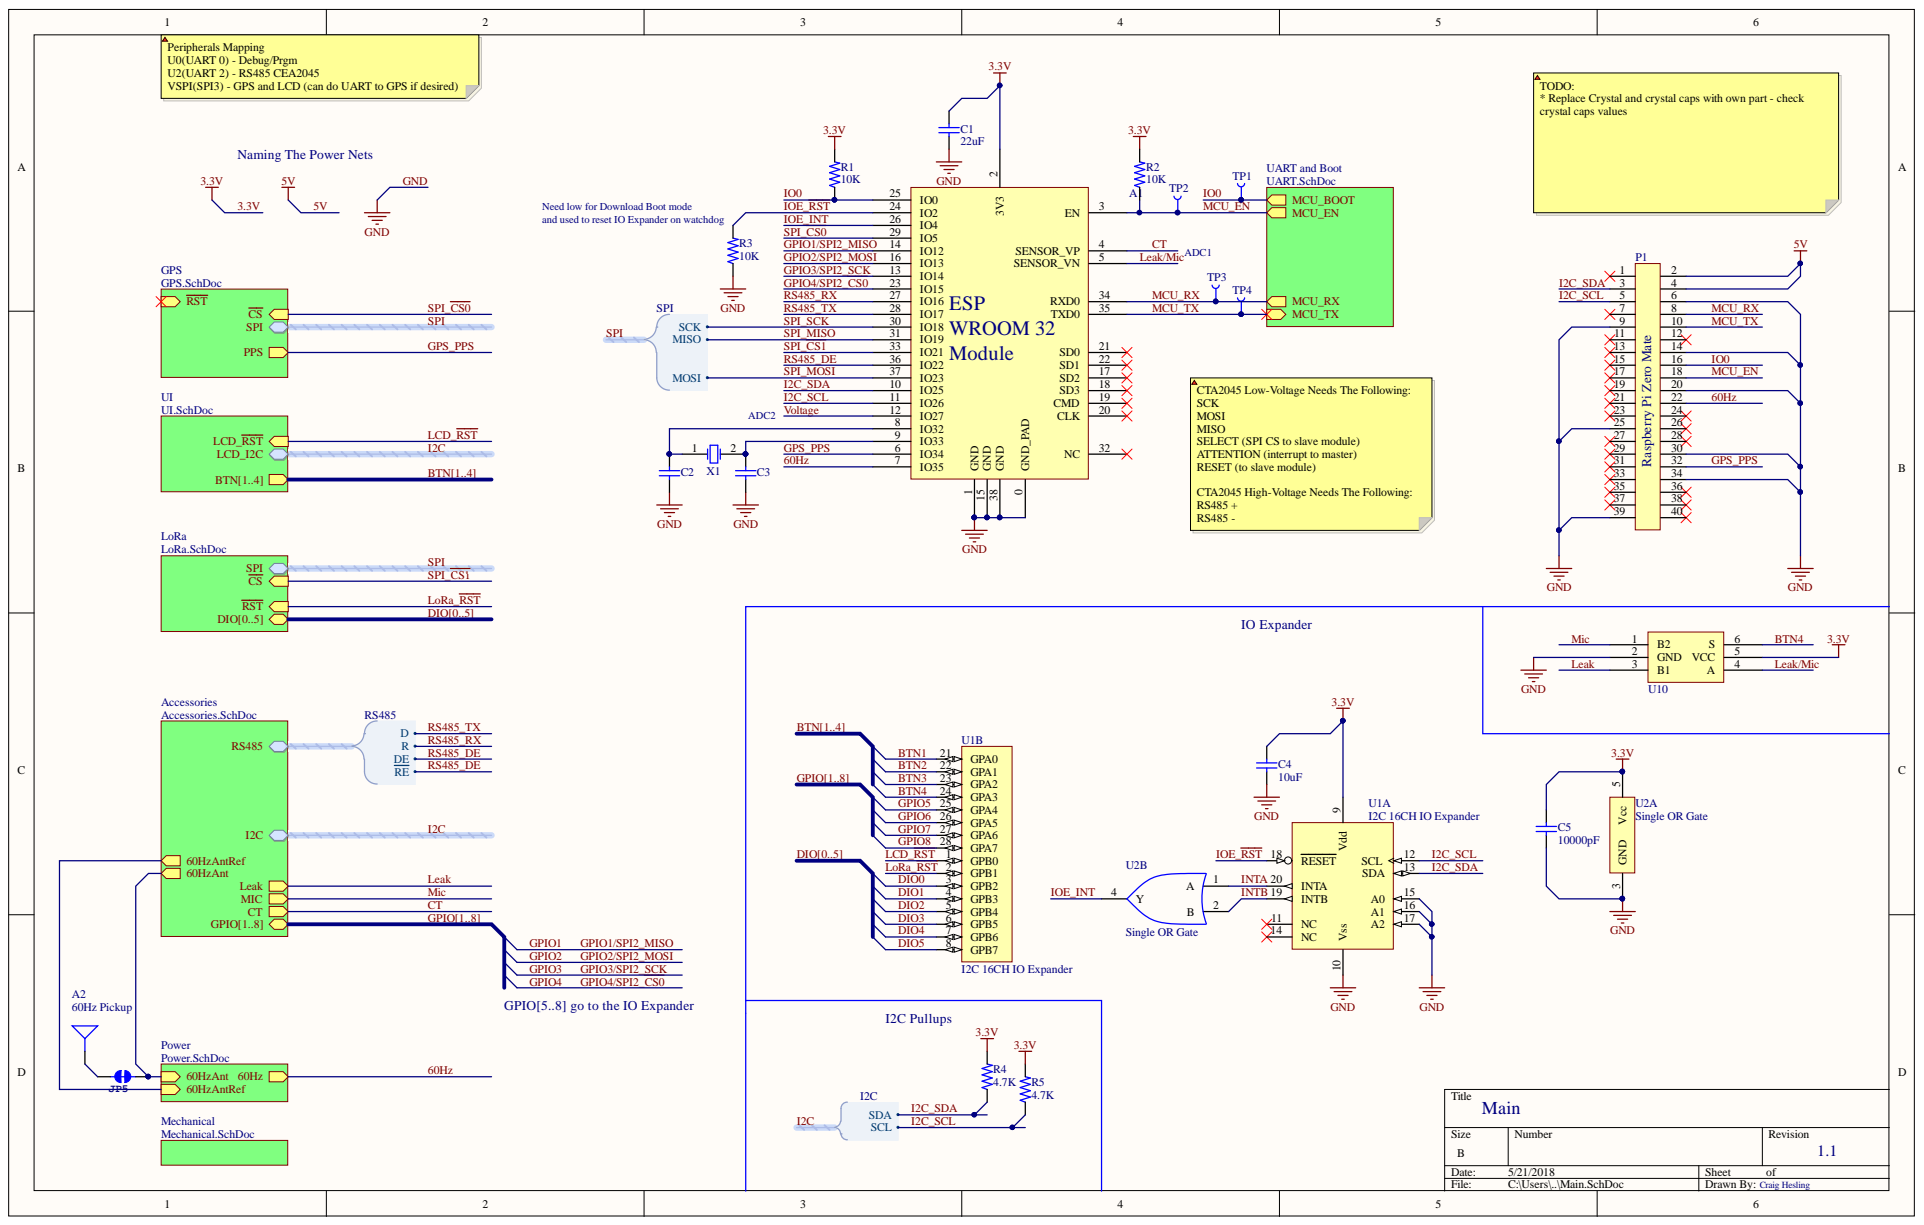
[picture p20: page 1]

Need low for Download Boot mode
and used to reset IO Expander on watchdog

tage Needs The Fol

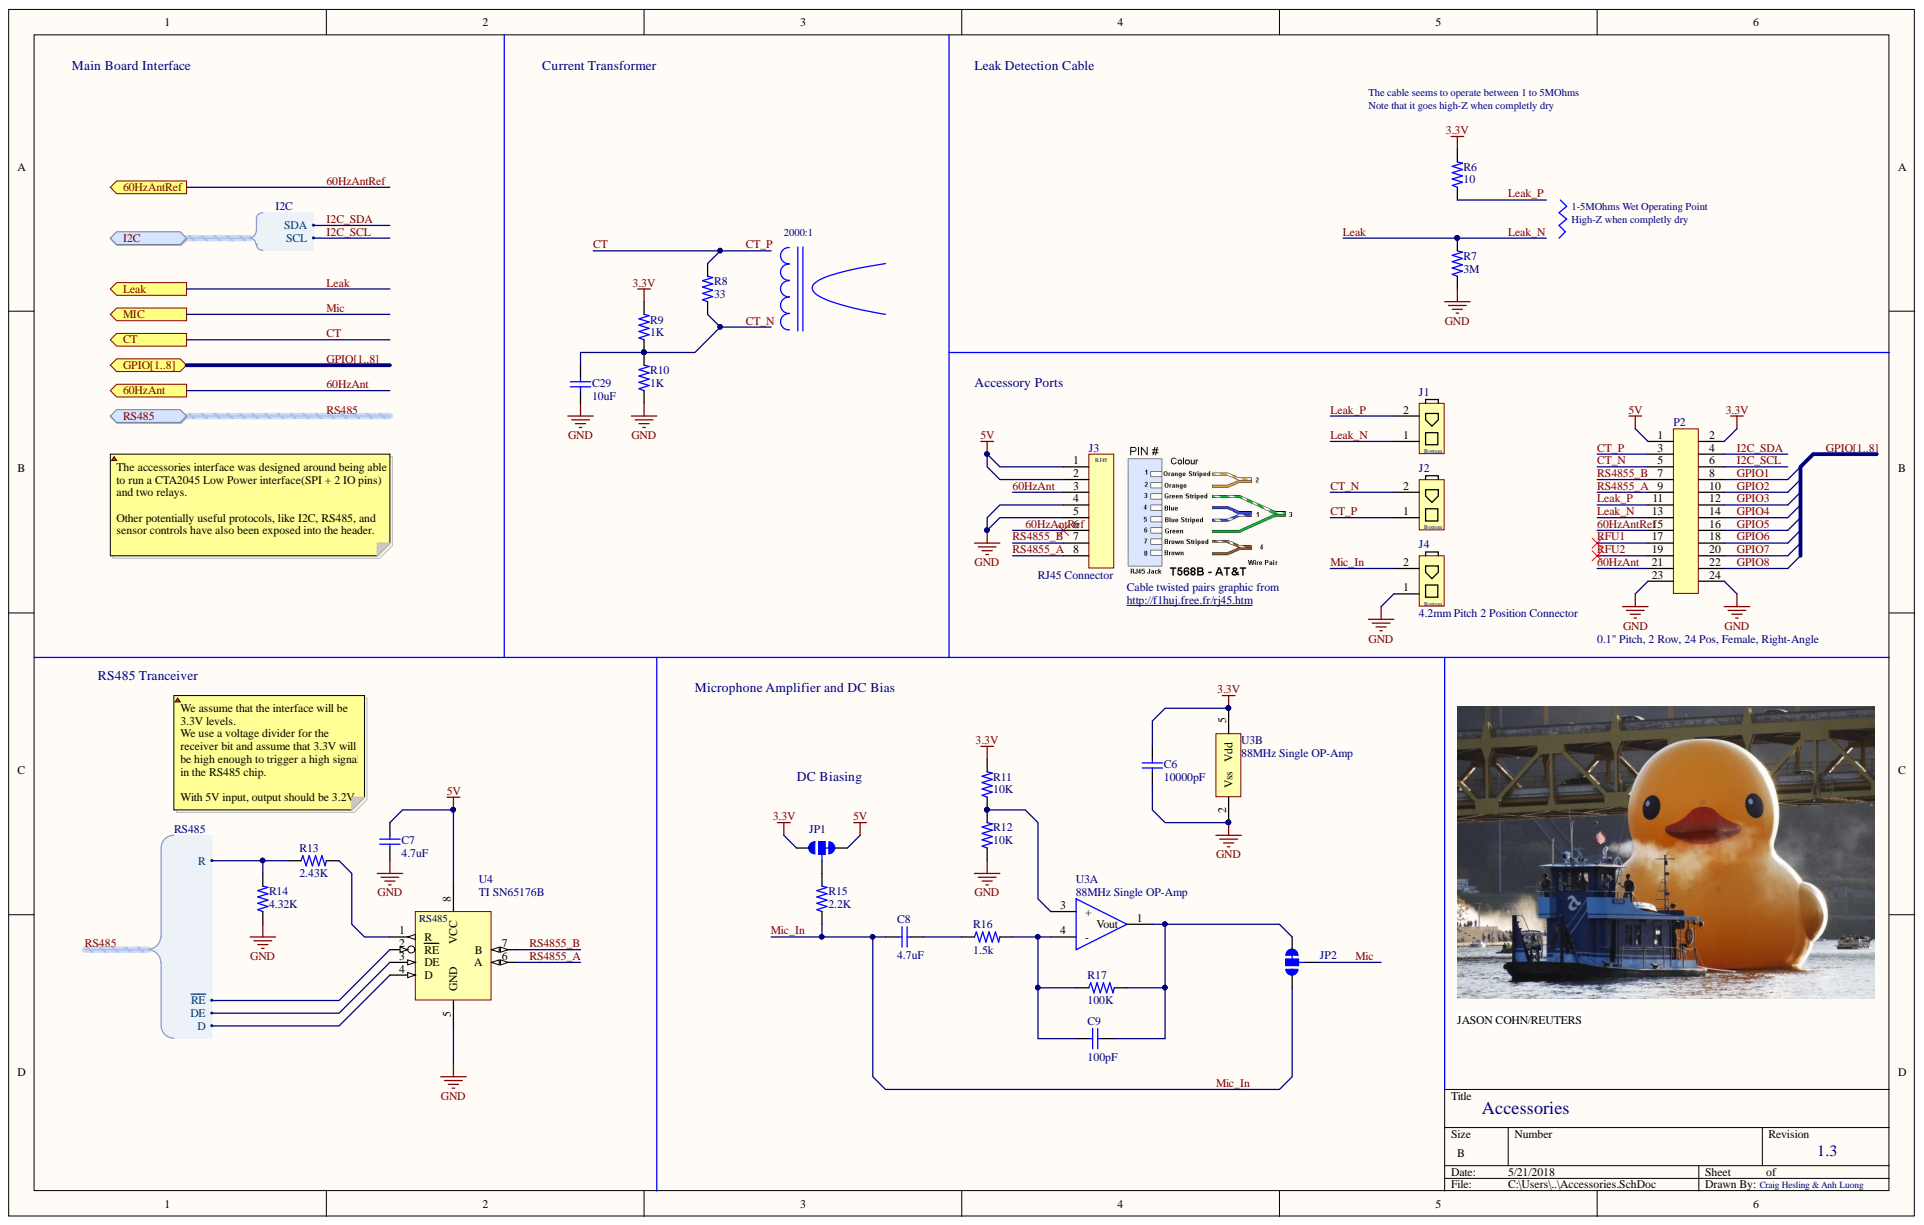
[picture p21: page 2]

The cable seems to operate between 1 to 5MOhms
Note that it goes high-Z when completly dry Leak_P Leak_N

1-5MOhms
High-Z when completly dry

igned around being able
face(SPI + 2 I

so been exposed into the header

tch, 2 Row, 24 Pos, Female, R

in the RS485 chip. With 5V input, output should be 3.2V | Amp l i D C 3.3V 88M Hz Single OP-3

3.3V level
We use a vol
receiver bi
be high enough to tr

sume that the inter
tage divider for the
t and as

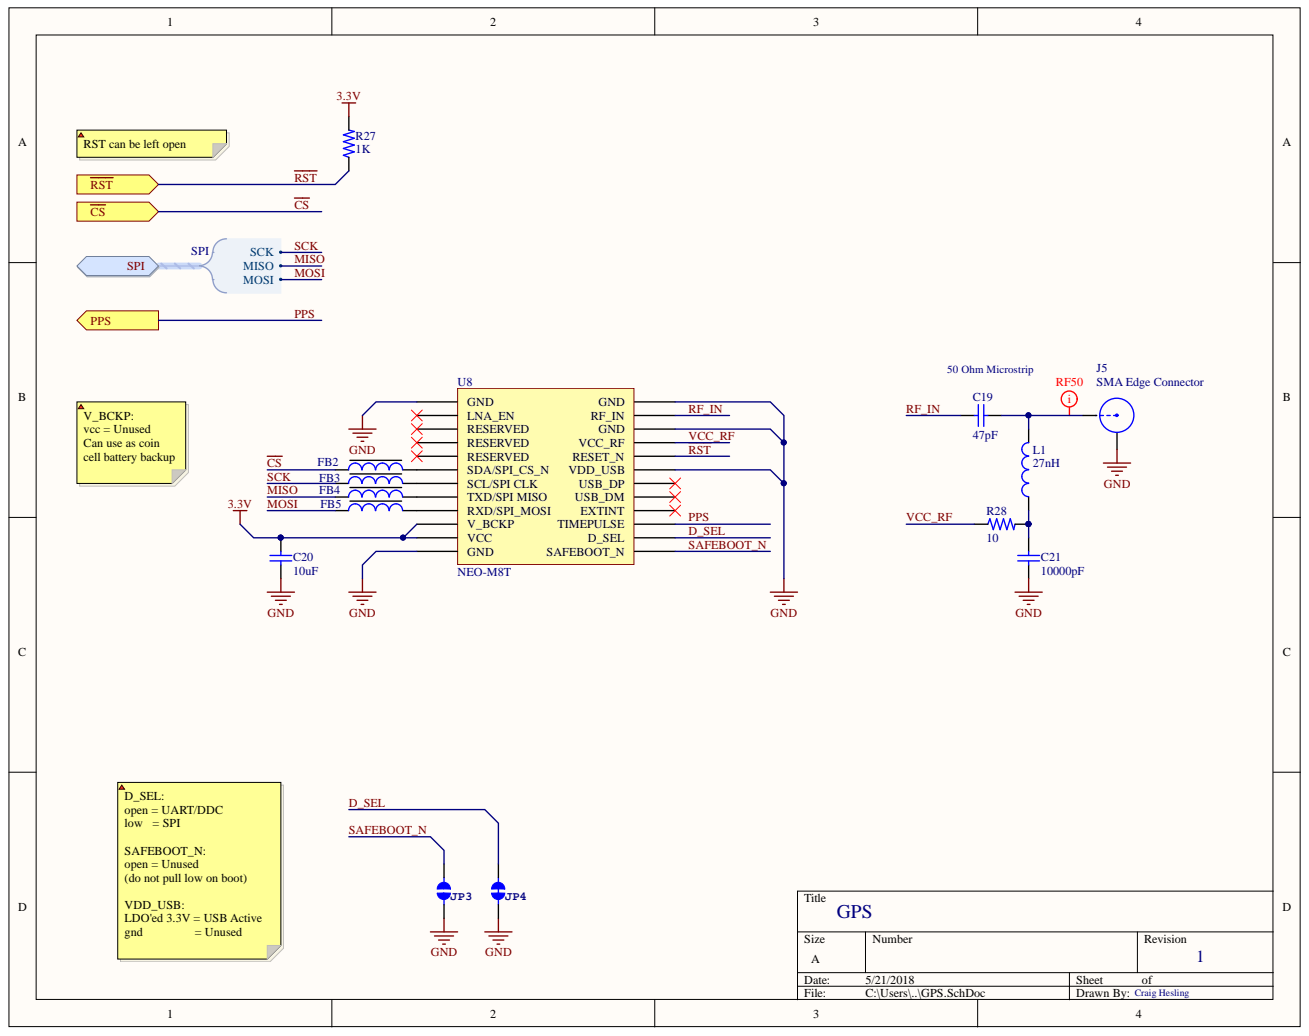
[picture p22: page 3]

RST can be left open

V_BCKP:
vcc = Unused
Can use as coin
cell battery backup

SAFEBOOT_N:
open = Unused
(do not pull low on boot)

VDD_USB:
LDO'ed 3.3V = USB Active

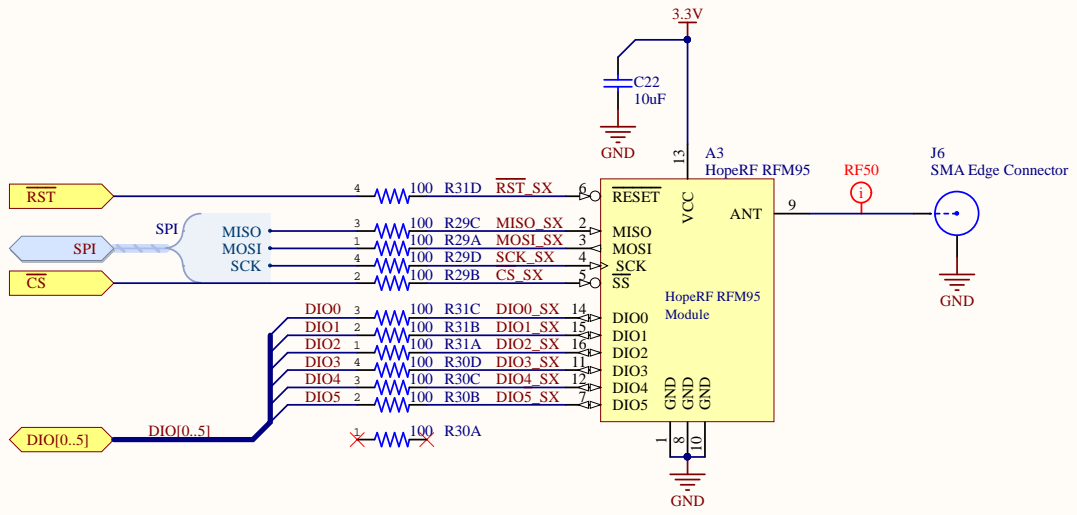
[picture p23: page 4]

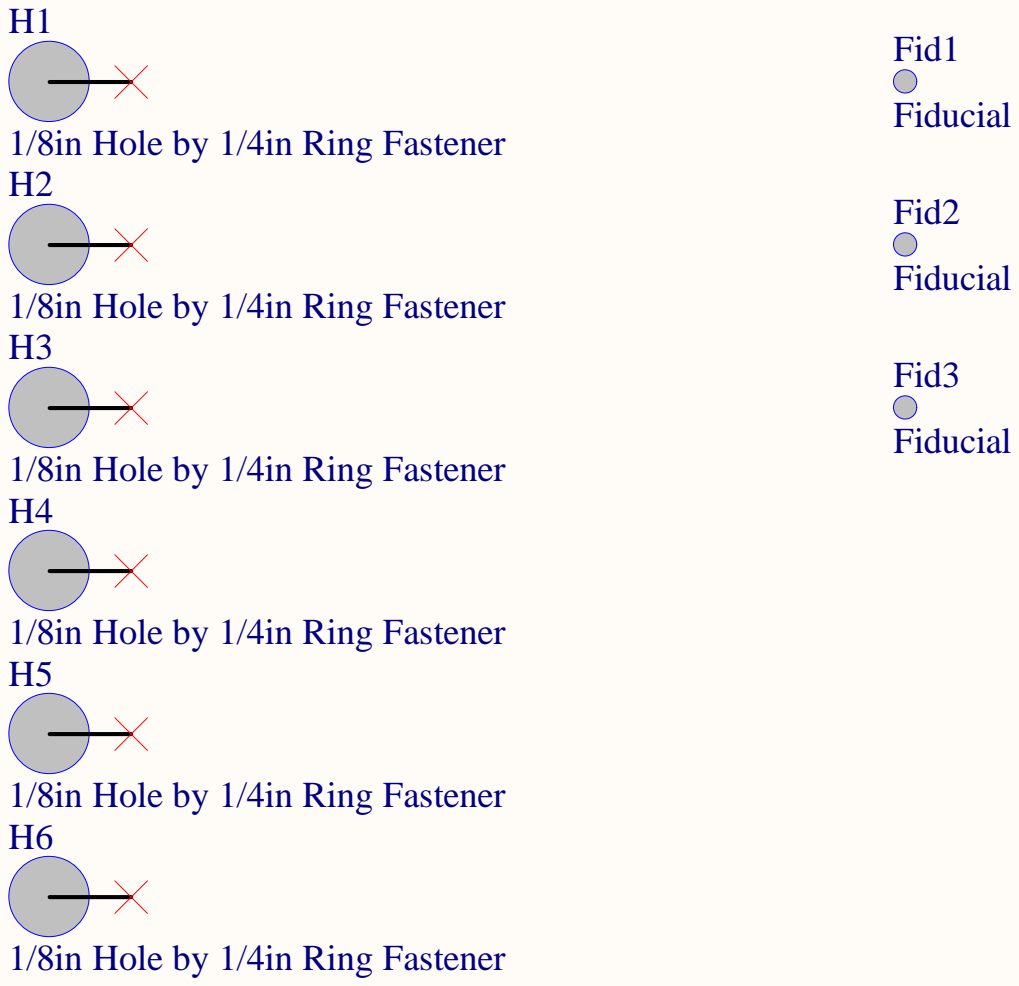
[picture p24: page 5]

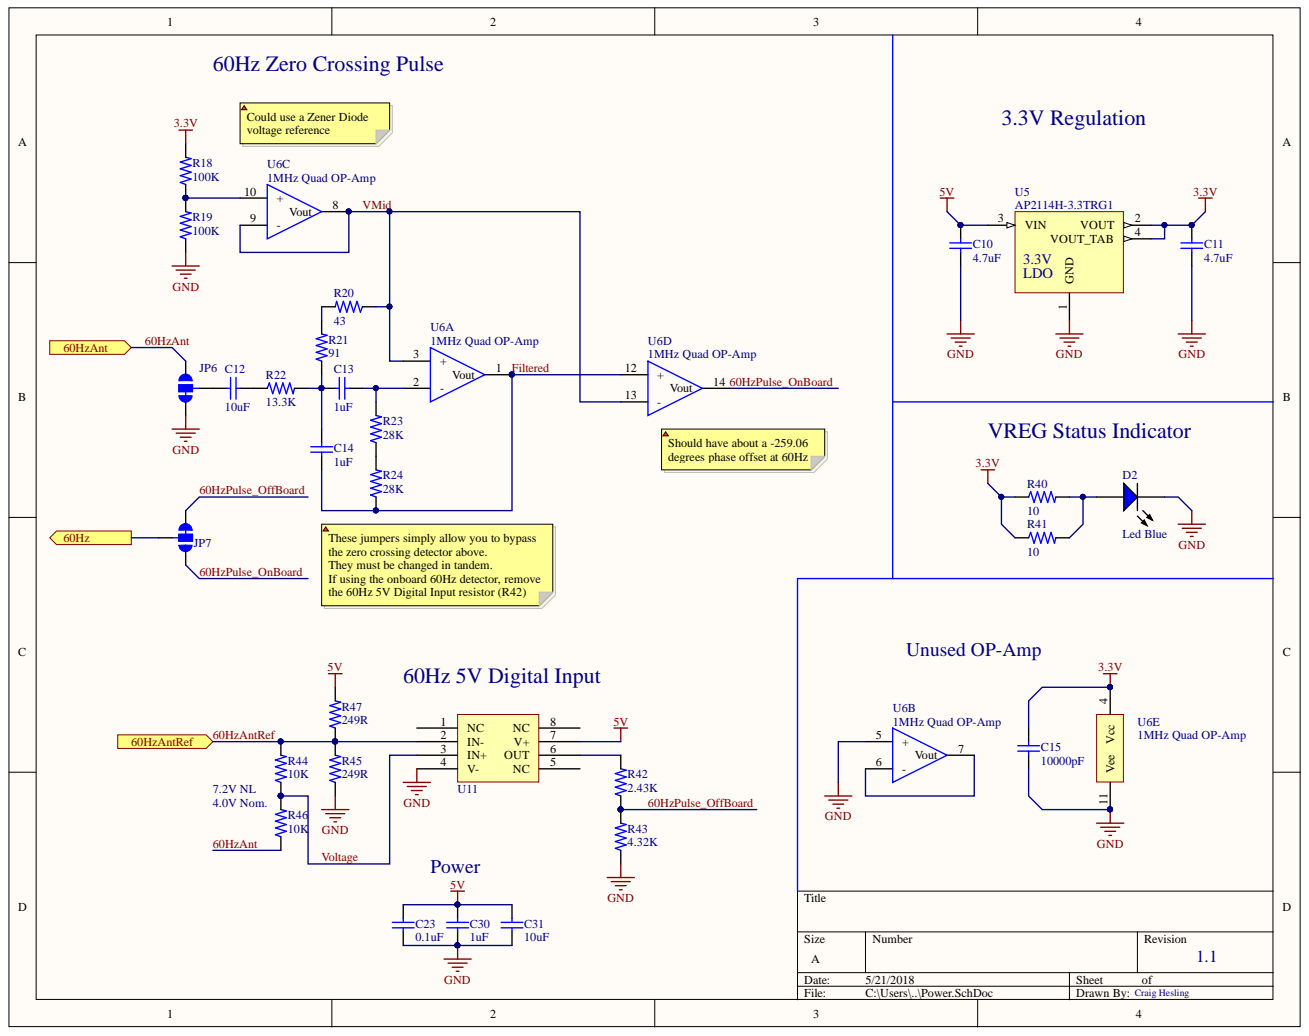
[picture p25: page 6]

Could use a Zener Diode
voltage reference

Should have about a -259.06
degrees phase offset at 60Hz

These jumpers simply allow you to bypass
the zero crossing detector above.
They must be changed in tandem.
If using the onboard 60Hz detector, remove
the 60Hz 5V Digital Input resistor (R42)

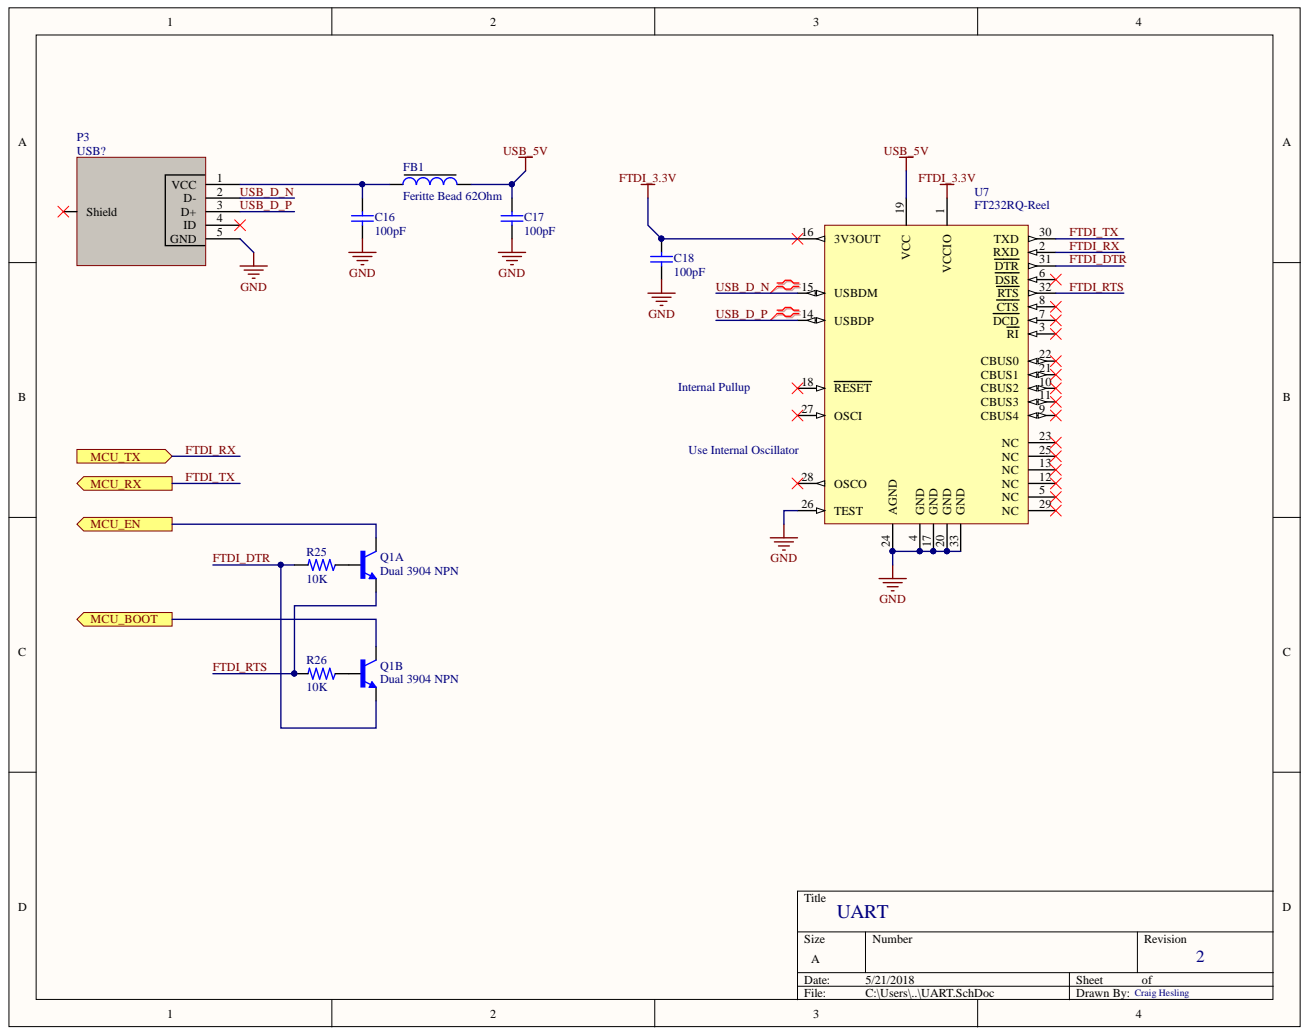
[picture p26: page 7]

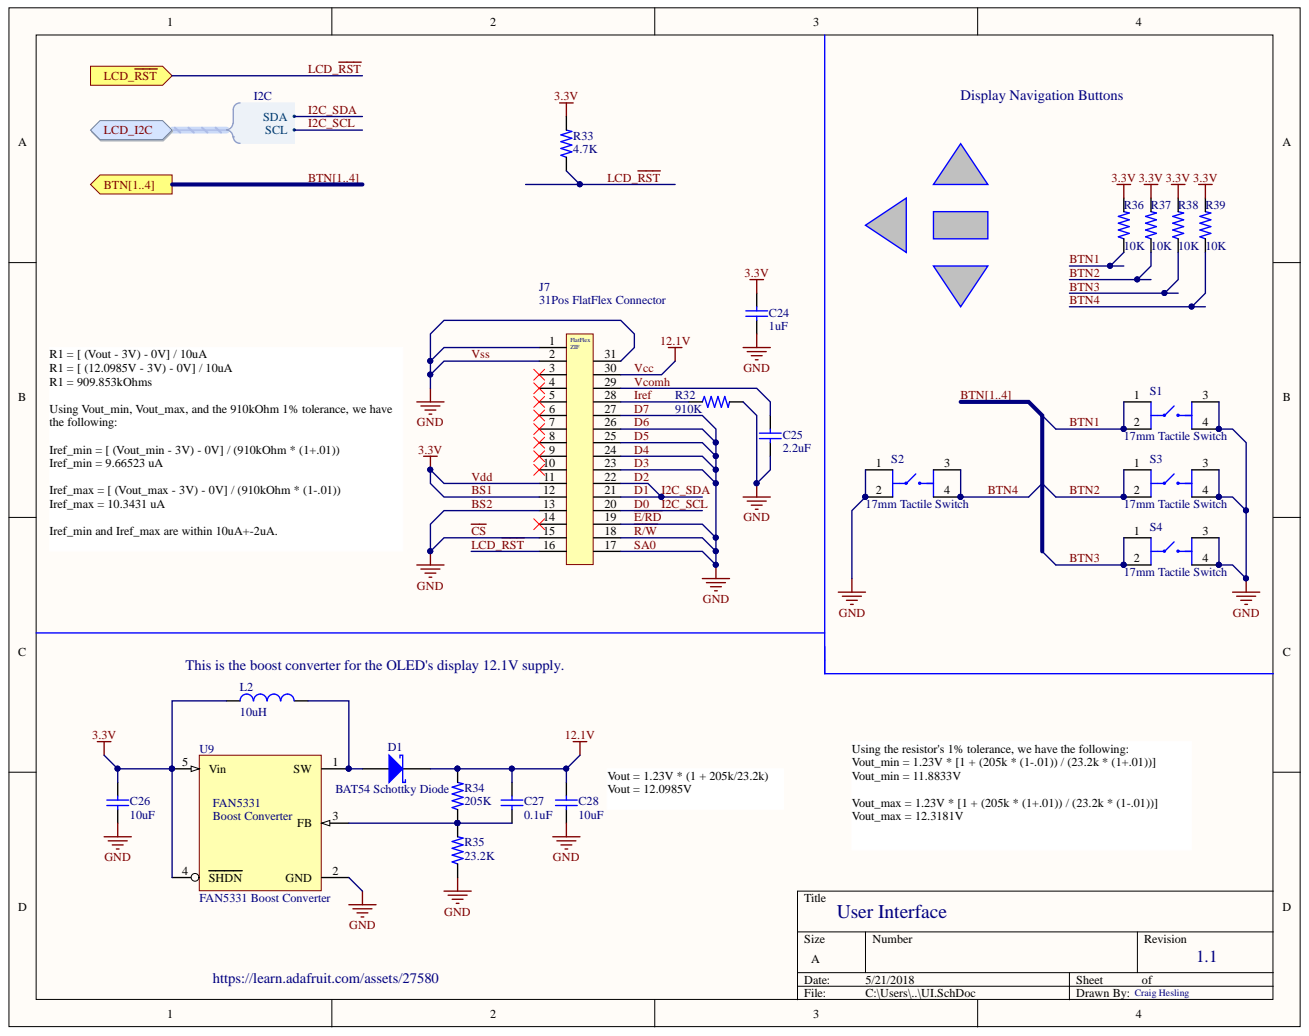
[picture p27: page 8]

This is the boost converter for the OLED's display 12.1V supply.

Using the resistor's 1% tolerance, we have the following:
Vout_min = 1.23V * [1 + (205k * (1-.01)) / (23.2k * (1+.01))]
Vout_min = 11.8833V

https://learn.adafruit.com/assets/27580

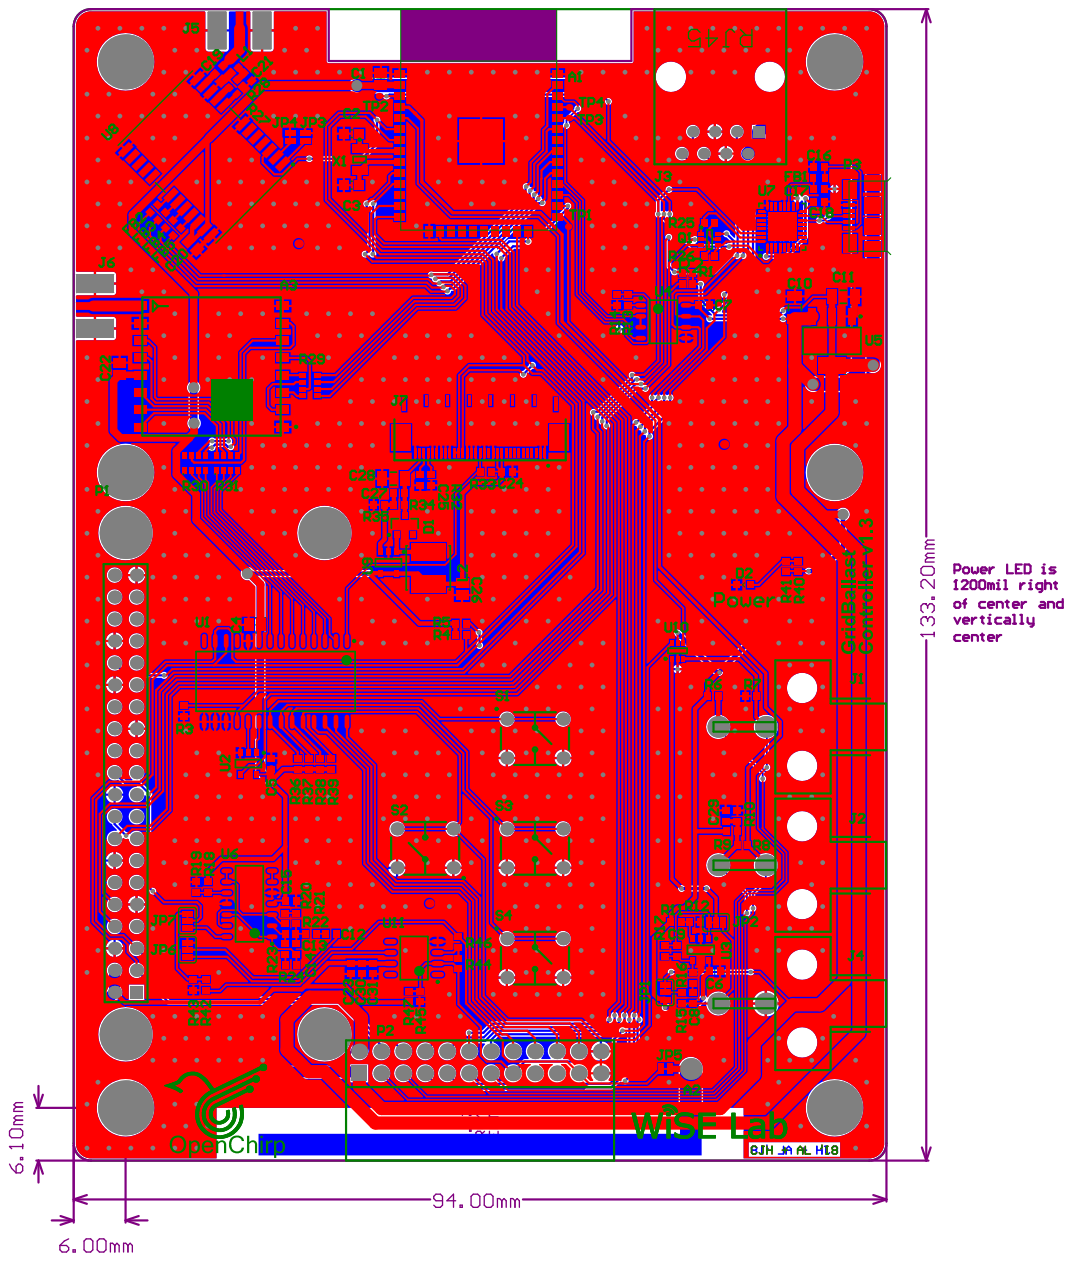
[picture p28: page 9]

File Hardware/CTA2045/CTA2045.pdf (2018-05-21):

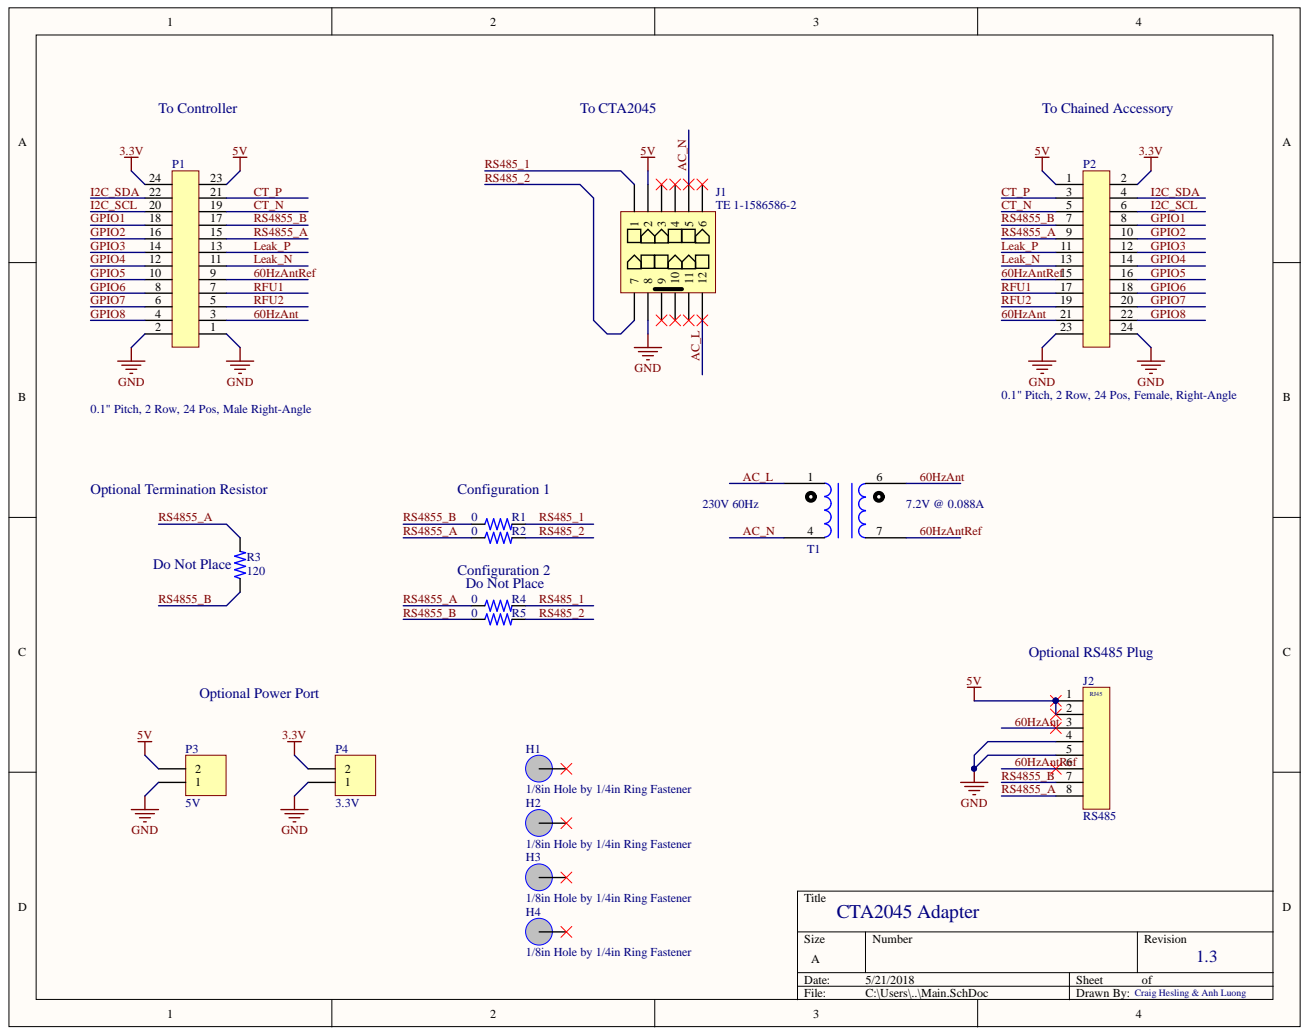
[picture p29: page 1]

GND
0.1" Pitch, 2 Row, 24 Pos, Female, Right-Angle

0.1" Pitch, 2 Row, 24 Pos, Male Right-Angle

1/8in Hole by 1/4in Ring Fastener

Craig Hesling & Anh Luong

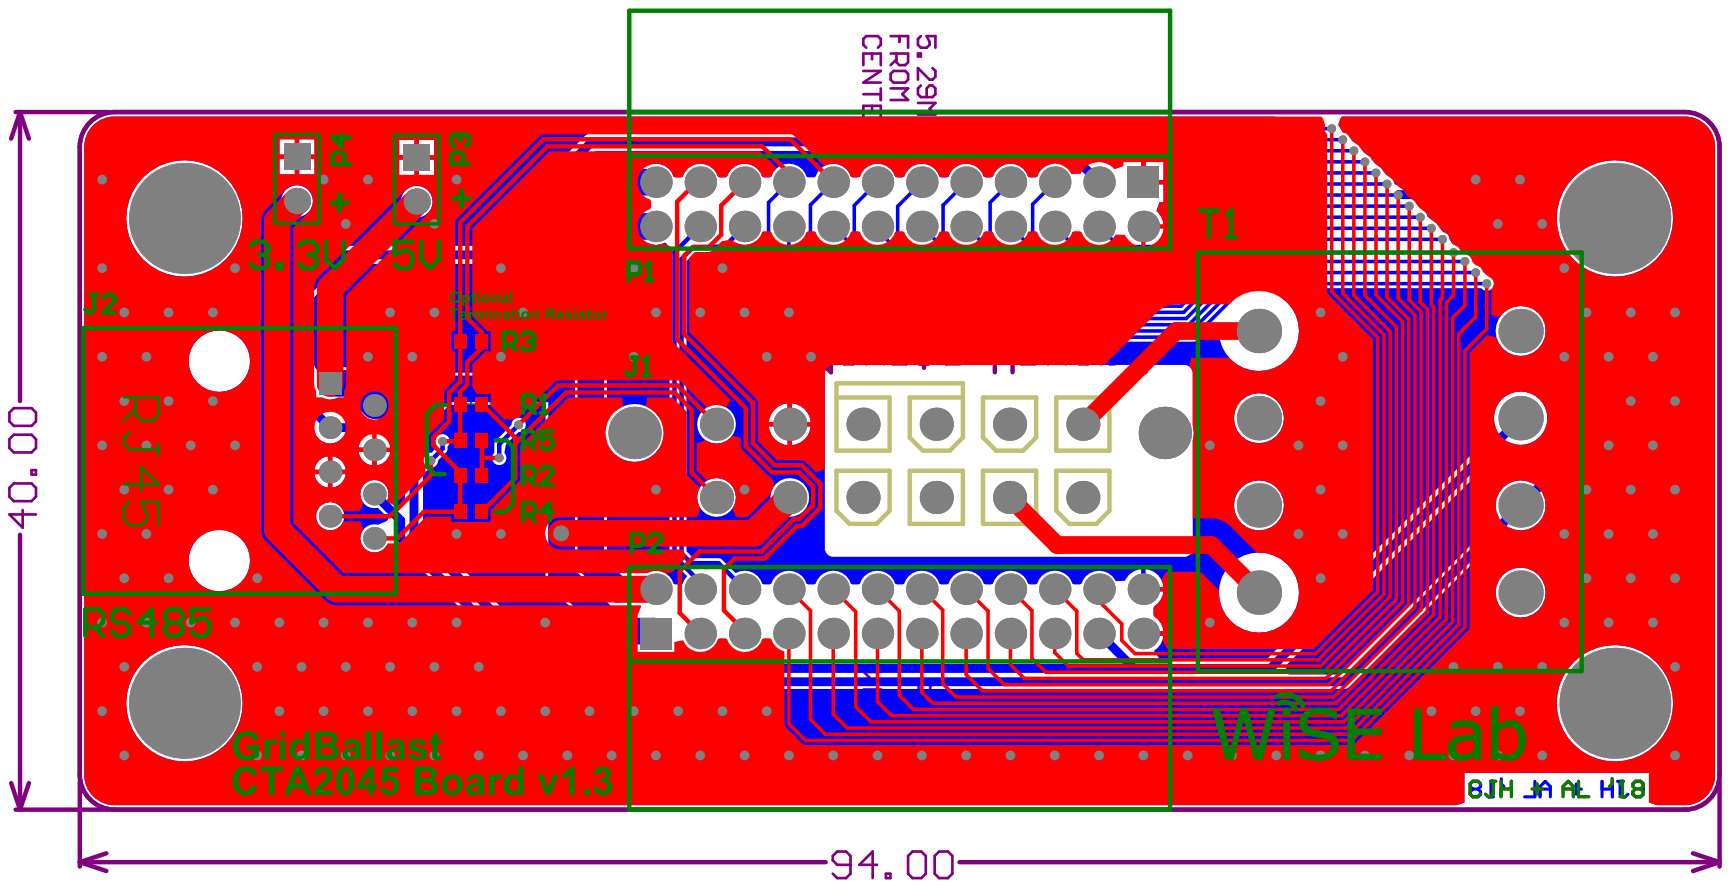
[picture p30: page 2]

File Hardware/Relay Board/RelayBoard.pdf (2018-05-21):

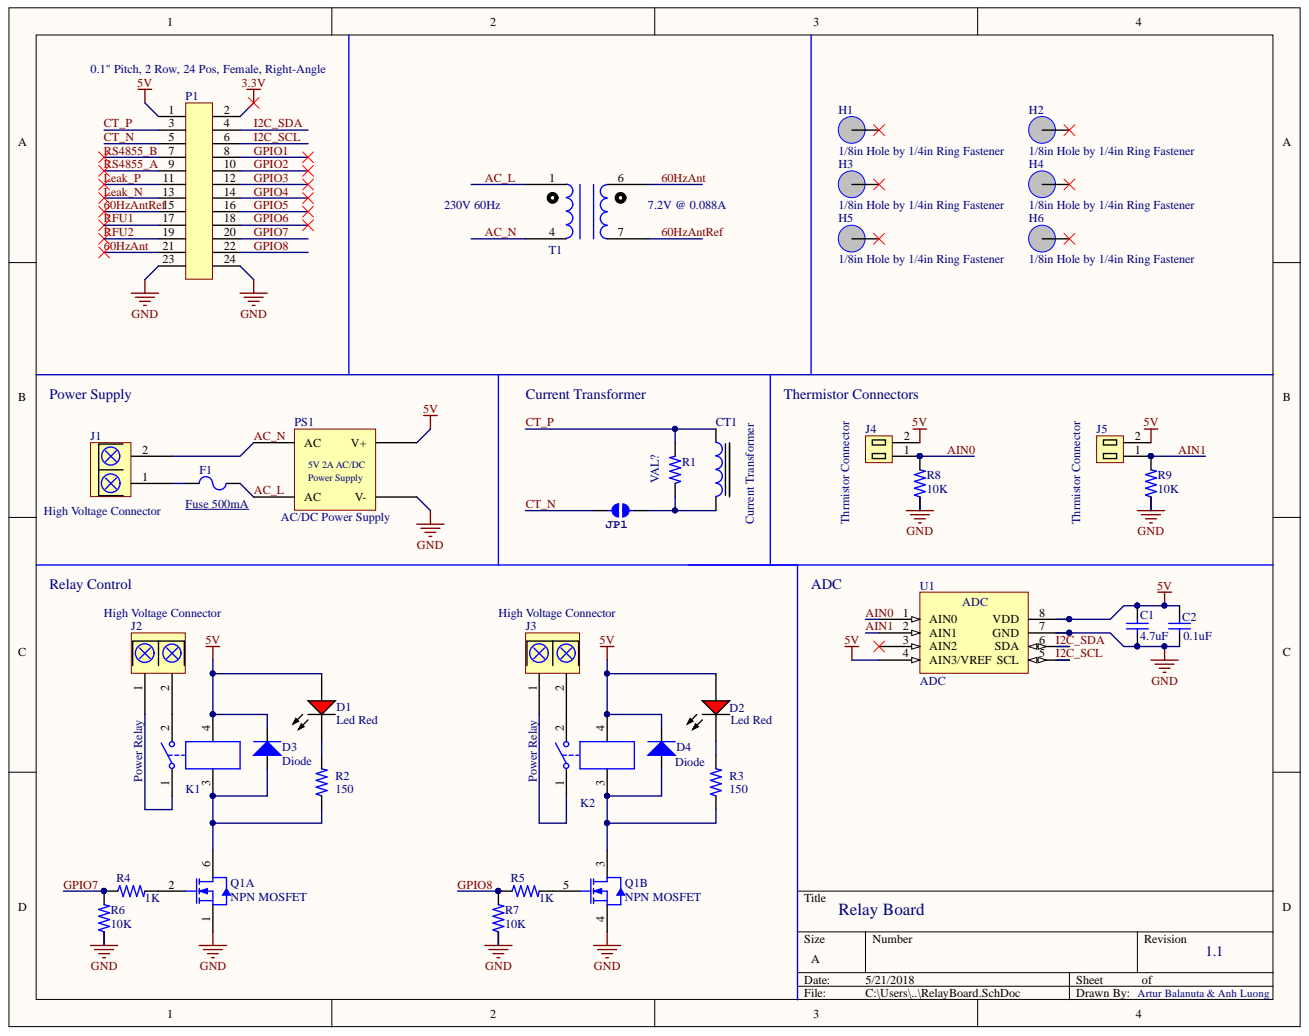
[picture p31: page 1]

0.1" Pitch, 2 Row, 24 Pos, Female, Right-Angle

1/8in Hole by 1/4in Ring Fastener

Power Supply
AC/DC Power Supply

Artur Balanuta & Anh Luong


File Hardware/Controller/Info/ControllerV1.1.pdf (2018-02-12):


Need low for Download Boot mode
and used to reset IO Expander on watchdog

tage Needs The Fol


The cable seems to operate between 1 to 5MOhms
Note that it goes high-Z when completly dry Leak_P Leak_N

1-5MOhms
High-Z when completly dry

Accesso r y Po r t s J 1 G D ight -Angl e

igned around being able
face(SPI + 2 I

so been exposed into the header

tch, 2 Row, 24 Pos, Female, R

in the RS485 chip. With 5V input, output should be 3.2V | Amp l i D C 3.3V 88M Hz Single OP-3

3.3V level
We use a vol
receiver bi
be high enough to tr

sume that the inter
tage divider for the
t and as


RST can be left open

V_BCKP:
vcc = Unused
Can use as coin
cell battery backup

SAFEBOOT_N:
open = Unused
(do not pull low on boot)

VDD_USB:
LDO'ed 3.3V = USB Active




Could use a Zener Diode
voltage reference

Should have about a -259.06
degrees phase offset at 60Hz

These jumpers simply allow you to bypass
the zero crossing detector above.
They must be changed in tandem.
If using the onboard 60Hz detector, remove
the 60Hz 5V Digital Input resistor (R42)



This is the boost converter for the OLED's display 12.1V supply.

Using the resistor's 1% tolerance, we have the following:
Vout_min = 1.23V * [1 + (205k * (1-.01)) / (23.2k * (1+.01))]
Vout_min = 11.8833V

https://learn.adafruit.com/assets/27580


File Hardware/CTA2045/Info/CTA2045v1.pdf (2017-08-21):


GND
0.1" Pitch, 2 Row, 24 Pos, Female, Right-Angle

0.1" Pitch, 2 Row, 24 Pos, Male Right-Angle

1/8in Hole by 1/4in Ring Fastener


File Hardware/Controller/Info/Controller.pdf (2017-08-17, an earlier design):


Peripherals Mapping
U0(UART 0) - Debug/Prgm
U2(UART 2) - RS485 CEA2045
VSPI(SPI3) - GPS and LCD (can do UART to GPS if desired)

TODO:
* Replace Crystal and crystal caps with own part - check
crystal caps values

Naming The Power Nets

Need low for Download Boot mode
and used to reset IO Expander on watchdog

Raspberry Pi Zero Mate

CTA2045 Low-Voltage Needs The Following:
SCK
MOSI
MISO
SELECT (SPI CS to slave module)
ATTENTION (interrupt to master)
RESET (to slave module)

GPIO[5..8] go to the IO Expander

Size B | Number | Revision 1

Date: 8/17/2017 | Sheet of
File: C:\Users\..\Main.SchDoc | Drawn By: Craig Hesling


The cable seems to operate between 1 to 5MOhms
Note that it goes high-Z when completly dry Leak_P Leak_N

1-5MOhms
High-Z when completly dry

igned around being able
face(SPI + 2 I

so been exposed into the header

tch, 2 Row, 24 Pos, Female, R

in the RS485 chip. With 5V input, output should be 3.2V | Amp D C 3.3V 88M Hz Single OP-3

3.3V level
We use a vol
receiver bi
be high enough to tr

sume that the inter
tage divider for the
t and as


RST can be left open

V_BCKP:
vcc = Unused
Can use as coin
cell battery backup

SAFEBOOT_N:
open = Unused
(do not pull low on boot)

VDD_USB:
LDO'ed 3.3V = USB Active




Could use a Zener Diode
voltage reference

Should have about a -259.06
degrees phase offset at 60Hz



This is the boost converter for the OLED's display 12.1V supply.

Using the resistor's 1% tolerance, we have the following:
Vout_min = 1.23V * [1 + (205k * (1-.01)) / (23.2k * (1+.01))]
Vout_min = 11.8833V

https://learn.adafruit.com/assets/27580


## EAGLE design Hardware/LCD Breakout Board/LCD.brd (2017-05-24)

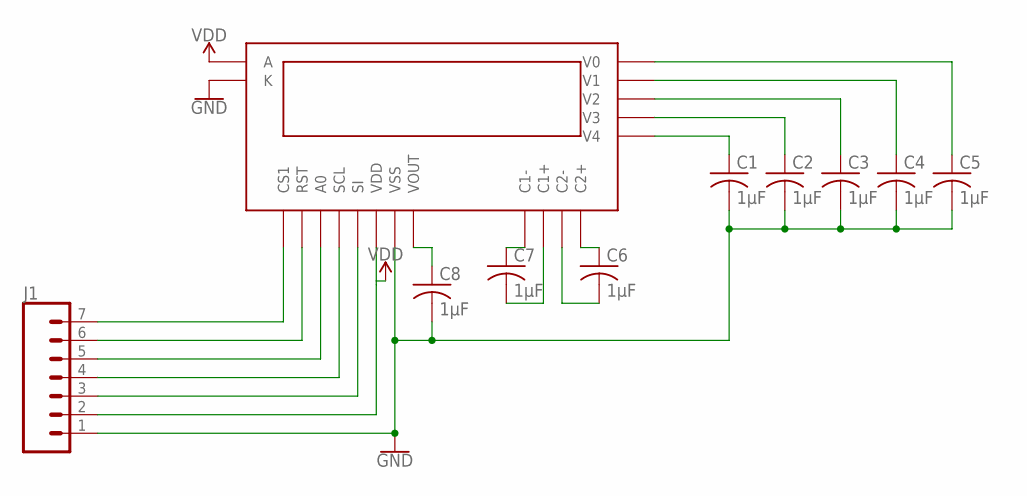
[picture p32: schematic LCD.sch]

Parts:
C1, C2, C3, C4, C5, C6, C7, C8: 1µF; C1206
J1: CONN_07; 1X07
U$1: LCD-NHD; NHD-C12832A1Z

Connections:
A0: J1.5, U$1.A0
CS1: J1.7, U$1.CS1
GND: C1.2, C2.2, C3.2, C4.2, C5.2, C8.2, J1.1, U$1.K, U$1.VSS
unnamed: C5.1, U$1.V0
unnamed: C4.1, U$1.V1
unnamed: C3.1, U$1.V2
unnamed: C2.1, U$1.V3
unnamed: C1.1, U$1.V4
unnamed: C7.1, U$1.C1-
unnamed: C7.2, U$1.C1+
unnamed: C6.1, U$1.C2+
unnamed: C6.2, U$1.C2-
RST: J1.6, U$1.RES (RST)
SCL: J1.4, U$1.SCL
SI: J1.3, U$1.SI
VDD: J1.2, U$1.A, U$1.VDD
VOUT: C8.1, U$1.VOUT

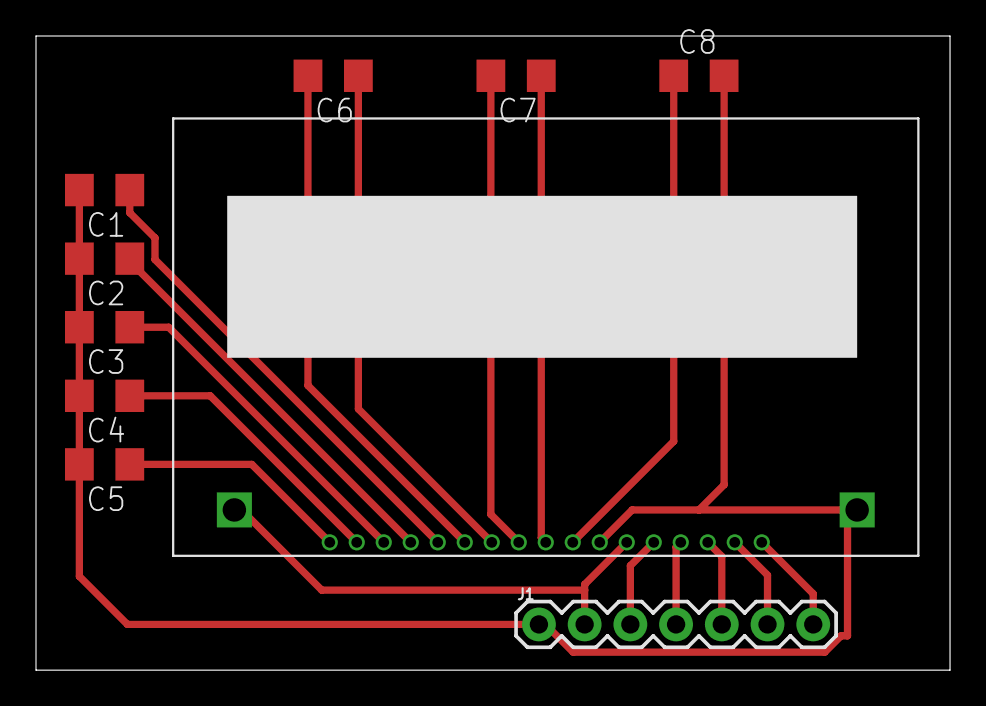
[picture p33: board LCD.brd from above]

Board: 2 copper layers, 50.8 x 35.2 mm, 10 parts (0 on the bottom side), 17 nets.

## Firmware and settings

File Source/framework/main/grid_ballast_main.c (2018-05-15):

/**
 * @file grid_ballast_main.c
 *
 * @brief main function that starts up the grid ballast system

 * @author Rohit Gaarg (rohitg1)
 * @author Vikram Shanker (vshanker@cmu.edu)
 */

#include <stdio.h>
#include <string.h> /* memset */
#include "rwlock.h"

#include "controller_module.h"
#include "esp_system.h"
#include "freertos/FreeRTOS.h"
#include "freertos/task.h"
#include "nvs_flash.h"
#include "sensing_module.h"

#include "Ada_MCP.h" // IO Expander Library
#include "generic_rw_i2c.h"  // generic I2C read/write functions

#include "system_state.h"
#include "wifi_module.h"
#include "lcd_module.h"
#include "frq_module.h"
#include "rs_485_module.h"
#include "button.h"
#include "controller_module.h"
#include "ct_module.h"
#include "driver/timer.h"
#include "util.h"
#include "driver/adc.h"
#include "esp_adc_cal.h"

bool State = true;


#define ESP_INTR_FLAG_DEFAULT 0

system_state_t gb_system_state;
rwlock_t system_state_lock;
rwlock_t i2c_lock;


#define PIN_MCP_RESET 2                   // I/O expander reset pin

#define PIN_SDA 25                        /*i2c pins */
#define PIN_SCL 26                       
#define I2C_MASTER_FREQ_HZ     100000     /* I2C master clock frequency */

#define LEVEL_HIGH 1
#define LEVEL_LOW 0


/**
 * @brief initialization task that starts all other threads
 *
 * @param pv_parameters - parameters for task being created (should be NULL)
 *
 * @return void
 */




void init_task( void *pv_parameters ) {

    gpio_install_isr_service(ESP_INTR_FLAG_DEFAULT);
    

    // temporary snippet to change thermostat set point
    rwlock_writer_lock(&system_state_lock);
    get_system_state(&gb_system_state);
    gb_system_state.set_point = 100;
    gb_system_state.threshold_overfrq = 60.01;
    gb_system_state.threshold_underfrq = 59.99;
    gb_system_state.mode =0;
    set_system_state(&gb_system_state);
    rwlock_writer_unlock(&system_state_lock);
    

    
    //wifi_init_task();
    //sensing_init_task();
    controller_init_task();

    

     printf("Initializing frq\n");
     frq_init_task();
     printf("Initializing rs485\n");

     button_init_task();

     printf("Initializing lcd\n");
     lcd_init_task();
        
     printf("Initialization done\n");

    
     rs485_init_task();
// 
      

      //ct_init_task();
       
        //vTaskDelay(500/portTICK_PERIOD_MS);

        while(1);
       
}
    


/**
 * @brief main function that starts the initialization task
 *
 * @return void
 */



void app_main( void ) 
{
    
    nvs_flash_init();
    /* initialize gb_system_state to 0's */
    memset(&gb_system_state, 0, sizeof(gb_system_state));
    rwlock_init(&system_state_lock);
    rwlock_init(&i2c_lock);
    printf("Intializing GridBallast system...\n");


    xTaskCreate( &init_task, "init_task", 4096, NULL, 1, NULL);
    

    gpio_pad_select_gpio(PIN_MCP_RESET);
    gpio_set_direction(PIN_MCP_RESET, GPIO_MODE_OUTPUT);
    gpio_set_level(PIN_MCP_RESET, 1);
  // // rwlock_writer_lock(&i2c_lock);
   generic_i2c_master_init (I2C_NUM_1, PIN_SCL, PIN_SDA, I2C_MASTER_FREQ_HZ);

    begin(0);

    pinMode(8,GPIO_MODE_OUTPUT);       // test o/p

    digitalWrite(8,0);

    vTaskDelay(0.05 / portTICK_PERIOD_MS);

    digitalWrite(8,1);

 //Characterize ADC at particular atten
    // esp_adc_cal_characteristics_t *adc_chars = calloc(1, sizeof(esp_adc_cal_characteristics_t));
    // esp_adc_cal_value_t val_type = esp_adc_cal_characterize(ADC_UNIT_1, ADC_ATTEN_DB_11, ADC_WIDTH_BIT_9, 1100, adc_chars);
    // //Check type of calibration value used to characterize ADC
    // if (val_type == ESP_ADC_CAL_VAL_EFUSE_VREF) {
    //     printf("eFuse Vref");
    // } else if (val_type == ESP_ADC_CAL_VAL_EFUSE_TP) {
    //     printf("Two Point");
    // } else {
    //     printf("Default");
    // }

    // while(1)
    // {

    // adc2_vref_to_gpio(26);

    // uint32_t reading =  adc1_get_raw(ADC1_CHANNEL_0);
    // uint32_t voltage = esp_adc_cal_raw_to_voltage(reading, adc_chars);

    // printf("%u\n",voltage);

    // vTaskDelay(2000 / portTICK_PERIOD_MS);
 

//}

}

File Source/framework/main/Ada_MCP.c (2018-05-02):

/*************************************************** 
 This is a library for the MCP23017 i2c port expander

 These displays use I2C to communicate, 2 pins are required to
 interface
 Adafruit invests time and resources providing this open source code,
 please support Adafruit and open-source hardware by purchasing
 products from Adafruit!

 Written by Limor Fried/Ladyada for Adafruit Industries.
 BSD license, all text above must be included in any redistribution
 ****************************************************/

/* ---------------------------------------------------------------
 *
 * Note for the ESP-32 IDF: The i2c subsystem is not initalized 
 * by any of this code.  You must do that before calling the 
 * begin() method of this class.
 *
 * See the generic_i2c_master_init() function in generic_i2c_rw.{h,cpp}
 *
 * ---------------------------------------------------------------
 */

#include <stdint.h>
#include "Ada_MCP.h"
#include <driver/gpio.h>
#include <driver/i2c.h>
#include "generic_rw_i2c.h"



static int bitRead(uint32_t x, uint8_t n) {
    return ((x & 1 << n) != 0);
}

static uint32_t bitWrite(uint32_t x, uint8_t n, uint8_t b) {
    return ((x & (~(1 << n))) | (b << n));
}

/**
 * Bit number associated to a give Pin
 */
uint8_t bitForPin(uint8_t pin){
    return pin % 8;
}

/**
 * Register address, port dependent, for a given PIN
 */
uint8_t regForPin(uint8_t pin, uint8_t portAaddr, uint8_t portBaddr) {
    return (pin < 8) ? portAaddr : portBaddr;
}


/**
 * Read a 16 bit register value
 */
uint16_t readRegisterWord(uint8_t addr) {
	return generic_read_i2c_register_word (MCP23017_ADDRESS | i2caddr, addr);
}

/**
 * Write a 16 bit register value
 */
void writeRegisterWord(uint8_t addr, uint16_t value) {
	generic_write_i2c_register_word (MCP23017_ADDRESS | i2caddr, addr, value);
}

/**
 * Reads a given register
 */
uint8_t readRegister(uint8_t addr){
	return generic_read_i2c_register (MCP23017_ADDRESS | i2caddr, addr);
}

/**
 * Writes a given register
 */
void writeRegister(uint8_t regAddr, uint8_t regValue){
	generic_write_i2c_register (MCP23017_ADDRESS | i2caddr, regAddr, regValue);
}


/**
 * Helper to update a single bit of an A/B register.
 * - Reads the current register value
 * - Writes the new register value
 */
void updateRegisterBit(uint8_t pin, uint8_t pValue, uint8_t portAaddr, uint8_t portBaddr) {
    uint8_t regValue;
    uint8_t regAddr = regForPin(pin, portAaddr, portBaddr);
    uint8_t bit = bitForPin(pin);

    regValue = readRegister(regAddr);

    // set the value for the particular bit
    regValue = bitWrite(regValue, bit, pValue);

    writeRegister(regAddr, regValue);
}

////////////////////////////////////////////////////////////////////////////////

/**
 * Initializes the MCP23017 given its HW selected address, see datasheet for Address selection.
 *
 * Note: Address means the actual address as set by the hardware pins, 0 to 7
 *
 * Just to be nice, only the lower 3 bits of the address are looked at, so if 
 * the user sends in the logical address, they don't get unexpected results.
 *
 */


void begin(uint8_t addr) {

    i2caddr = addr & 7;

    //Wire.begin();

    // set defaults!
    // all inputs on port A and B
    writeRegisterWord(MCP23017_IODIRA, 0xffff);

}

/**
 * Initializes the default MCP23017, with 000 for the configurable part of the address
 */
/*
void begin(void) {
    begin();
}*/

/**
 * Sets the pin mode to either INPUT or OUTPUT
 */
void pinMode(uint8_t p, uint8_t d) {
    updateRegisterBit(p, (d==GPIO_MODE_INPUT), MCP23017_IODIRA, MCP23017_IODIRB);
}

/**
 * Reads all 16 pins (port A and B) into a single 16 bits variable.
 */
uint16_t readGPIOAB() {
    return readRegisterWord (MCP23017_GPIOA);
}

/**
 * Read a single port, A or B, and return its current 8 bit value.
 * Parameter b should be 0 for GPIOA, and 1 for GPIOB.
 */
uint8_t readGPIO(uint8_t b) {

    return readRegister(b==0 ? MCP23017_GPIOA : MCP23017_GPIOB);
}

/**
 * Writes all the pins in one go. This method is very useful if you are implementing a multiplexed matrix and want to get a decent refresh rate.
 */
void writeGPIOAB(uint16_t ba) {
    writeRegisterWord(MCP23017_GPIOA, ba);
}

void digitalWrite(uint8_t pin, uint8_t d) {
    uint8_t gpio;
    uint8_t bit = bitForPin(pin);


    // read the current GPIO output latches
    uint8_t regAddr = regForPin(pin, MCP23017_OLATA, MCP23017_OLATB);
    gpio = readRegister(regAddr);

    // set the pin and direction
    gpio = bitWrite(gpio, bit, d);

    // write the new GPIO
    regAddr = regForPin(pin, MCP23017_GPIOA, MCP23017_GPIOB);
    writeRegister(regAddr, gpio);
}

void pullUp(uint8_t p, uint8_t d) {
    updateRegisterBit(p, d, MCP23017_GPPUA, MCP23017_GPPUB);
}

uint8_t digitalRead(uint8_t pin) {
    uint8_t bit = bitForPin(pin);
    uint8_t regAddr = regForPin(pin, MCP23017_GPIOA, MCP23017_GPIOB);
    return (readRegister(regAddr) >> bit) & 0x1;
}

/**
 * Configures the interrupt system. both port A and B are assigned the same configuration.
 * Mirroring will OR both INTA and INTB pins.
 * Opendrain will set the INT pin to value or open drain.
 * polarity will set LOW or HIGH on interrupt.
 * Default values after Power On Reset are: (false,flase, LOW)
 * If you are connecting the INTA/B pin to arduino 2/3, you should configure the interupt handling as FALLING with
 * the default configuration.
 */
void setupInterrupts(uint8_t mirroring, uint8_t openDrain, uint8_t polarity){
    // configure the port A
    uint8_t ioconfValue=readRegister(MCP23017_IOCONA);
    ioconfValue = bitWrite(ioconfValue,6,mirroring);
    ioconfValue = bitWrite(ioconfValue,2,openDrain);
    ioconfValue = bitWrite(ioconfValue,1,polarity);
    writeRegister(MCP23017_IOCONA,ioconfValue);

    // Configure the port B
    ioconfValue=readRegister(MCP23017_IOCONB);
    ioconfValue = bitWrite(ioconfValue,6,mirroring);
    ioconfValue = bitWrite(ioconfValue,2,openDrain);
    ioconfValue = bitWrite(ioconfValue,1,polarity);
    writeRegister(MCP23017_IOCONB,ioconfValue);
}
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

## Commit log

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2017-05-22 PCB Files and LCD Screen Board Added
    [LCD.GBL, LCD.GBO, LCD.GBS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]
2017-05-24 Initial: Schematic complete and initial layout work
    [CEA2045.SchDoc, GPS.SchDoc, JTAG.SchDoc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]
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2017-06-21 Removed Relays and Thermistors
    [Relay.SchDoc, Termistor Channel.SchDoc]
2017-06-21 Moved Altium project to Hardware/
    [CEA2045.SchDoc, GPS.SchDoc, JTAG.SchDoc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]
2017-06-21 Compressed Main board Altium project into Hardware folder
    [CEA2045.SchDoc, GPS.SchDoc, JTAG.SchDoc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]
2017-06-21 Finished Hardware directory migration
    [CEA2045.SchDoc, GPS.SchDoc, JTAG.SchDoc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]
2017-06-27 Changed CEA2045 to AC version with an RS485 tranceiver and 3.3v level shift logic
    [CEA2045.SchDoc]
2017-06-27 Changed JTAG to full size Tag Connect
    [JTAG.SchDoc]
2017-06-27 Added in new 1A 3.3V LDO
    [Power.SchDoc]
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2017-07-03 FIniished 60Hz detector and new 3.3V LDO
    [Power.SchDoc]
2017-07-03 Using AC 2045 and RS485 transceiver
    [CEA2045.SchDoc]
2017-07-03 Using onboard FT232RQ + MicroUSB and two NPNs to program and boot
    [UART.SchDoc]
2017-07-03 Renamesd MCU to Main
    [Main.SchDoc]
2017-07-03 Connected almost all elements
    [Main.SchDoc]
2017-07-06 Pulled in ublox Library and organized all into Libraries directory
    [Water Heater Chip.PrjPcb]
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2017-07-07 Updated RS485 Schematic Symbol
    [CEA2045.SchDoc]
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2017-07-11 Removed SD Card and moved Sensors to Accessories
    [Accessories.SchDoc, Main.SchDoc, Sensors.SchDoc]
2017-07-12 Removed CEA2045, JTAG, and SD interface
    [CEA2045.SchDoc, JTAG.SchDoc, SD.SchDoc]
2017-07-12 Finalized Accessories schematic interface and added external header
    [Accessories.SchDoc]
2017-07-12 Changed LCD to UI schematic and updated Main
    [Main.SchDoc, UI.SchDoc]
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2017-07-12 Changed RF class to RF50
    [GPS.SchDoc]
2017-07-13 Changed 27nH inductor to a 1.7GHz specific one
    [GPS.SchDoc]
2017-07-13 Added 10uF on VCC of GPS
    [GPS.SchDoc]
2017-07-17 Finished all buffering and biasing circuits and headers in Accessories. Only need to add 3.5mm headers.
    [Accessories.SchDoc]
2017-07-17 Finished all components in Main. Only need RPi heade connections and 60Hz PCB antenna
    [Main.SchDoc]
2017-07-20 Finished Accessories Module with Connectors
    [Accessories.SchDoc]
2017-07-21 Decoupling caps, LCD_RST, and organization
    [Main.SchDoc, UI.SchDoc]
2017-07-25 Added flat flex ZIP and boost converter for OLED to UI
    [UI.SchDoc]
2017-07-28 Added four navigation tactile buttons
    [UI.SchDoc]
2017-07-28 Added Pittsburgh Rubber Duck
    [Accessories.SchDoc]
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2017-07-31 Craushed a TODO and updated PDF
    [UI.SchDoc]
2017-07-31 Annotated all components and updated PDF
    [Accessories.SchDoc, GPS.SchDoc, LoRa.SchDoc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]
2017-07-31 Added no ERC to RPi extra pins
    [Main.SchDoc]
2017-07-31 Fixed PPS labeling
    [Main.SchDoc]
2017-08-01 Turned off Warnings for Nets with multiple names
    [Water Heater Chip.PrjPcb]
2017-08-01 Fixed D1 off-grid warning
    [UI.SchDoc]
2017-08-01 Fixed RS485_CTRL harness mismatch
    [Accessories.SchDoc]
2017-08-01 Fixed all schematic errors and warning
    [Main.SchDoc, UART.SchDoc]
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2017-08-01 Organized Main schematic a bit more
    [Main.SchDoc]
2017-08-01 Cleaned up UI schematic and regenerated PDF
    [UI.SchDoc]
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2017-08-02 Modified Relay Board Placement in the Project
    [Water Heater Chip.PrjPcb]
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2017-08-02 Moved Libraries location in project
    [Water Heater Chip.PrjPcb]
2017-08-02 Removed relay board schematic and board file
    [Water Heater Chip.PrjPcb]
2017-08-02 Moved Hardware/Main to Hardware/Controller with new project
    [Accessories.SchDoc, Controller.PrjPcb, GPS.SchDoc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]
2017-08-02 Fixed ublox library
    [Controller.PrjPcb]
2017-08-02 Moved Relay Board to separate Project
    [Relay Board.PrjPcb, Relay Board.SchDoc]
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2017-08-03 Added voltage stabilization cap on 1.65V CT bias
    [Accessories.SchDoc]
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2017-08-10 Changed RPi Header to new RPi Zero component
    [Main.SchDoc]
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2017-08-10 Flipped IOE interrupt pins going into OR gate
    [Main.SchDoc]
2017-08-10 Fixed 3.3V decoupling cap in UI
    [UI.SchDoc]
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2017-08-14 Removed decoupling cap C23 due to closeness to regulator cap
    [UI.SchDoc]
2017-08-14 Named power nets to force pretty labels in PCB layout
    [Main.SchDoc]
2017-08-14 Fixed the Duck on Accessories schematic
    [Accessories.SchDoc]
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2017-08-14 Rearranged the ompamps used on the 60Hz detector
    [Power.SchDoc]
2017-08-15 Swapped a couple nets to fix routing problems
    [Main.SchDoc]
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2017-08-16 Changed GPS and LoRa radio antenna connectors to SMA
    [GPS.SchDoc, LoRa.SchDoc]
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2017-08-17 Fixes for Relay Board V1
    [PCBv2.PcbDoc, RelayBoard.PcbDoc, RelayBoard.PrjPcb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]
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2017-08-21 Moved two bottom layer traces to allow connecting the ground planes
    [CTA2045v1.PcbDoc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]
2017-08-21 A few more modifications to PCB traces for CTA2045 v1
    [CTA2045v1.PcbDoc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]
2017-08-21 A few more last minute changes to traces and GND planes
    [CTA2045v1.PcbDoc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]
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2018-02-08 Added bypass for 60Hz detector and a blue VREG status LED to Power schematic
    [Power.SchDoc]
2018-02-08 Made small cap C28 wiring change for Anh
    [UI.SchDoc]
2018-02-08 Added 5V and 60HzAnt to the RJ45 connection in Accessories schematic
    [Accessories.SchDoc]
2018-02-08 Changed I2C lines with GPS_PPS and 60Hz signals on the MCU
    [Main.SchDoc]
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2018-02-08 Created PCB V1.1 - Work In Progress
    Changes Routed:
    * I2C, GPS_PPS, and 60Hz pin remaped
    * Power LED
    * 60Hz detector bypass
    Changes Needing Routing:
    * RJ45 5V and 60Hz
    [Controller.PrjPcb]
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2018-02-08 add Max's 60Hz detection to both relay and cta2045 boards
    [CTA2045.PrjPcb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]
2018-02-09 Added voltage divider for 60Hz Digital input 5V to 3.3V level shifting
    [Power.SchDoc]
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2018-02-13 fixing some minor formatting
    [grid_ballast_main.c]
2018-02-13 fixing all the compilation errors from various modules
    [rs_485_module.c]
2018-03-04 Fix I2C issues by disabling internal pullups and fix compilation errors
    [frq_module.c, grid_ballast_main.c]
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2018-05-21 hardware version 1.3, hardware bug fixes
    [Accessories.SchDoc, CTA2045.PrjPcb, CTA2045v1.2.PcbDoc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]
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

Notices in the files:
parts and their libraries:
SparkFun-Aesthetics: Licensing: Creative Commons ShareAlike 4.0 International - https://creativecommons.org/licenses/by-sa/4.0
